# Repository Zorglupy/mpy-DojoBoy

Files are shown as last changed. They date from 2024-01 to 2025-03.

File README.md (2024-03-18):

# DojoBoy



The DojoBoy console is a DIY handheld game console project based on MicroPython

The main objectives of the project are:
- Cheap and easy to make with common components (no exotic components, custom PCB or universal PCB)
- Simple assembly with reduced tooling (soldering iron, screwdriver, Dremel tool)
- Easy printing of the case (5 parts only without supports)
- Game coding easy with only MicroPython libraries (no custom C codes, orginal MicroPython image based)
  - v 1.0 : All In One library
  - v 2.0 (WIP): Module with libraries (multiple objects) : object oriented coding, vector methods, extended features...

# Hardware

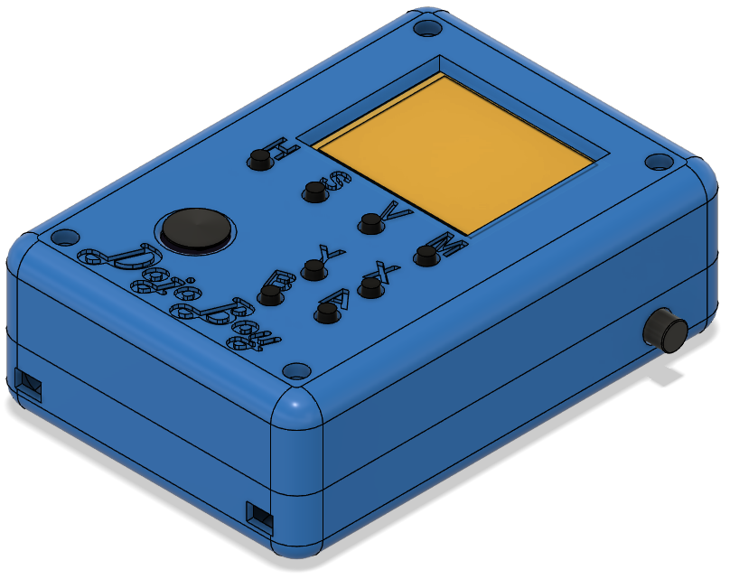
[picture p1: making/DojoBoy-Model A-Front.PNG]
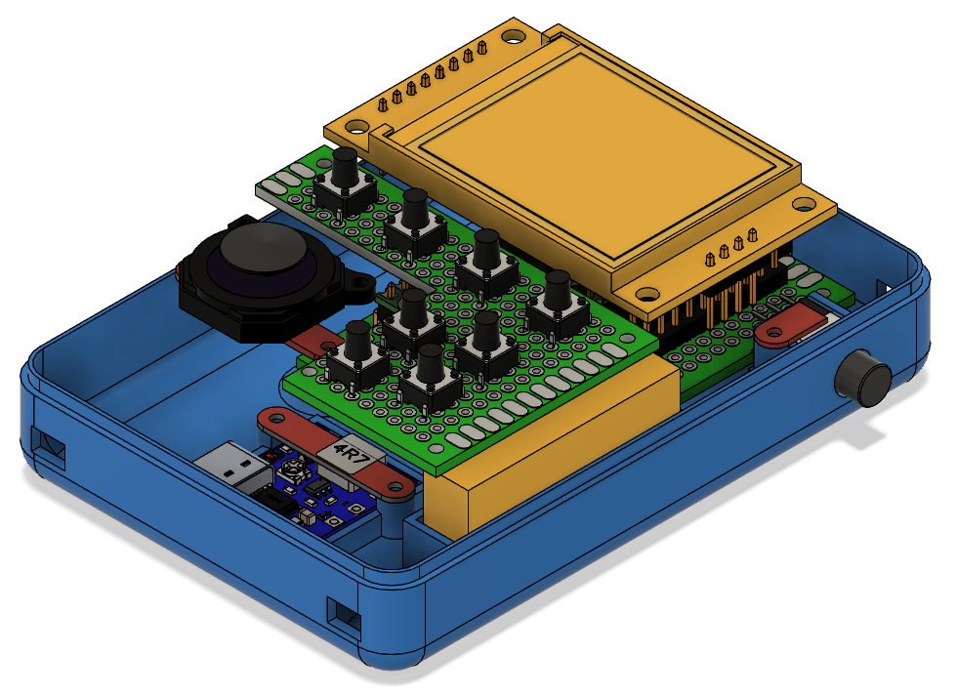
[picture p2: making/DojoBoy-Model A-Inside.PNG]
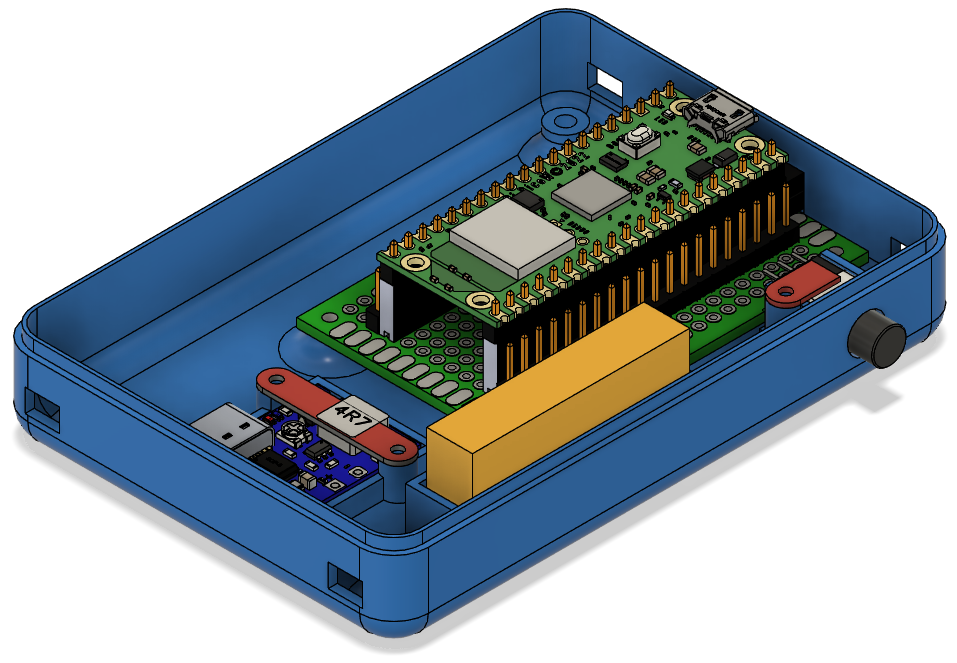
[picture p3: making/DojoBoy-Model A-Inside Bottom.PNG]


Multiple platforms are compatible/available:
- Raspberry Pi Pico or Pico W board and RP2040 clones
- LILYGO® T8 V1.7.1 ESP32 board.
- VCC-GND Studio YD-ESP32-S3 (DevKitC 1 clone)

Specs:
- Display:
  - ST7735 160x128 1.8"
  - ST7789 240x240 1.54"
  - ILI9341 320x240 3.2"
  - SSD1309 128x64 2.42"
- LiPo battery with charge management
- Joystick + 8 buttons
- 2 beeper channels (PWM)
- Expansion port (I2C, GPIO, I2S, SPI)
- SD card
- 3D Printable case

Schema :
DojoBoy-Wiring-Amp-Speaker-V2_bb

| Raspberry Pi Pico GPIO | Items Pin |
|--- |:-: |
| GPIO00 | A Button  |
| GPIO01 | B Button  |
| GPIO02 | X Button  |
| GPIO03 | Y Button  |
| GPIO04 | Ext Port - I2C 0 SDA |
| GPIO05 | Ext Port - I2C 0 SCL |
| GPIO06 | Home Button  |
| GPIO07 | Start Button  |
| GPIO08 | Volume Button  |
| GPIO09 | Menu Button  |
| GPIO10 | Ext Port - I2C 1 SDA  |
| GPIO11 | Ext Port - I2C 1 SCL  |
| GPIO12 | Display - SPI 1 A0 / DC  |
| GPIO13 | Display - SPI 1 CS  |
| GPIO14 | Display - SPI 1 SCK / CLK  |
| GPIO15 | Display - SPI 1 MOSI  |
| GPIO16 | Ext Port - SPI 0 MISO  |
| GPIO17 | Ext Port - SPI 0 CS  |
| GPIO18 | Ext Port - SPI 0 SCK / CLK  |
| GPIO19 | Ext Port - SPI 0 MOSI  |
| GPIO20 | Display - RST / Reset  |
| GPIO21 | PWM Sound Channel 0  |
| GPIO22 | PWM Sound Channel 1  |
| GPIO26 | Joystick X  |
| GPIO27 | Joystick Y  |
| GPIO28 | Display - LED  |
| 3.3V | Output 3.3V Power  |
| VSYS | Input 5V Power from Bat. Charger  |
| VBUS | Output 5V Power to Bat. Charger  |

# Wiring

DojoBoy-Board-V1_bb

# PCB
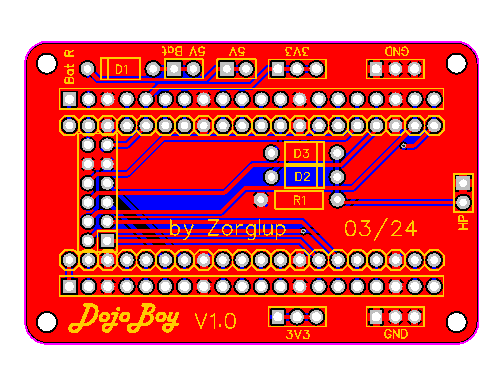
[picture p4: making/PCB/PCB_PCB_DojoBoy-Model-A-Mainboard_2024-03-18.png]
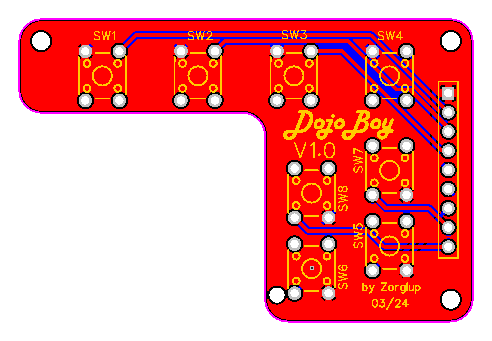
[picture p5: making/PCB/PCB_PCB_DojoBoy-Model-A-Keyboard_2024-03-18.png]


# Software

See Cheat Sheet file in Doc folder... 

Sources and inspirations :

- https://gist.github.com/samneggs
- https://github.com/harlepengren/PicoGame
- https://github.com/YouMakeTech/Pi-Pico-Game-Boy
- https://github.com/HalloSpaceBoy5/PicoBoy
- https://github.com/MLXXXp/Arduboy2
- https://github.com/peterhinch
- https://github.com/mchobby
- and more....

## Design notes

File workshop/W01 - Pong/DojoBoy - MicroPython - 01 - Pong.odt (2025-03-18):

DojoBoy - Pong

Cet atelier a pour objectif d’examiner les bases de la programmation en Micropython (Python) de la console DojoBoy et de créer un jeu inspiré du jeu Pong.

Au terme de celui-ci, tu seras capable de :

- Initialiser la console
- Afficher un objet à l’écran
- Déplacer un objet à l’écran
- Faire une boucle finie et infinie
- Utiliser les boutons de la console
- Définir une fonction

Pour comprendre les étapes de cet atelier, il est préférable que tu aies déjà appris les bases de la programmation avec Scratch et que tu comprennes ce qu’est une « variable », une « condition » et une « boucle ».

Le code dans ces pages n’est pas complet. Il est indispensable d’ajouter et adapter le code pour arriver à l’objectif. Fais-toi aider par un coach si tu es perdu ou que tu ne comprends pas !

Les challenge en fin d’étapes vont te permette d’expérimenter ton code et de mieux le comprendre. Ne les passe pas trop vite… 😉

# Initialisation du DojoBoy

L’accès aux fonctions qui permettent d’utiliser l’écran, les boutons et le son de la console sont rassemblés dans un « objet ».

Tous les programmes que tu vas écrire pour la console devront commencer par « importer » cet objet (rendre disponible l’objet pour le code qui va suivre). Il faut donc commencer les programmes par les lignes suivantes.

from dojoboy_v1 import DojoBoy

Cette ligne signifie qu’il faut importer l’objet « Dojo Boy » qui se trouve dans le module « dojoboy_v1 ». Nous examinerons dans un autre atelier ce qu’est un « module » et un « objet » dans le langage Python. Ne t’y attarde pas maintenant 😉

Il faut ensuite « instancier » cet objet (créer cet objet et lui donner un nom) pour ensuite l’utiliser dans nos programmes. Lors de la création de cet objet, des paramètres de configuration seront ajoutés pour configurer l’écran et les boutons de la console.

Quelques paramètres sont disponibles pour définir des paramètres particuliers.

Il n’est pas utile de s’étendre sur tous ces paramètres. Un seul est pratique pour débuter, il s’agit du paramètre pour activer ou désactiver l’écran d’accueil au démarrage d’un programme.

Pour créer l’objet DojoBoy avec l’écran d’accueil, il faut utiliser la commande suivante :

djb = DojoBoy()

Pour l’objet DojoBoy sans l’écran d’accueil:

djb=DojoBoy(show_intro=False)

Maintenant, commençons à programmer la console ! 👍

# Etape 1 : Premier programme...

Commençons par examiner comment afficher une « balle » à l’écran...

Les premières commandes du programme vont définir la position où la balle doit être affichée sur l’écran.

Nous allons donc définir les variables pos_x et pos_y et les initialiser avec les valeurs de la position sur la grille de pixels de l’écran.

L’illustration suivante représente l’écran de la console. Le pixel à la position 0,0 se trouve en haut à gauche. L’axe des X est horizontal (la largeur de l’écran, « width » en anglais) et l’axe Y est vertical (la hauteur de l’écran, « height » en anglais).

L’écran du DojoBoy est composé suivant le type d’écran de 240 ou 160 points sur la largeur et 240 ou 128 points sur la hauteur.

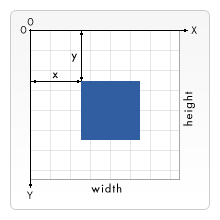
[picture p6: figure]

Pour afficher la balle au milieu de l’écran 160x128 points, il faut donc initialiser les variables de la manière suivante :

pos_x = 80

pos_y = 64

Il faut ensuite définir le diamètre en point (pixel) de la balle.

ball_size = 3 # ball radius

On peut remarquer en fin de ligne le caractère # qui permet d’ajouter des commentaires dans le programme. Tout ce qui suit ce caractère sur une même ligne n’est pas pris en compte dans le programme.

Les lignes suivantes vont ensuite afficher une balle au centre de l’écran.

djb.display.ellipse(pos_x, pos_y, ball_size, ball_size, djb.display.RED_H, True) #draw ball

djb.display.show() # show screen

La fonction « djb.display.ellipse » signifie « dessine sur l’écran de la console » (djb.display) « un ovale » (ellipse). Ici, c’est un ovale particulier car il a la forme d’un cercle.

Les paramètres qui suivent se basent sur les variables définies avant.

- pos_x : position du centre du cercle sur l’axe X
- pos_y : position du center du cercle sur l’axe Y
- ball_size,ball_size : défini le rayon du cercle
- djb.display.RED_H : défini la couleur de cercle
- True : indique le cercle doit être rempli de couleur

La fonction précédente ne montre pas directement le contenu de l’écran. Il faut utiliser la fonction djb.display.show() pour cela.

Challenge

- Change la couleur de la balle
- Change la taille de la balle
- Affiche la balle dans le haut de l’écran
- Affiche la balle à gauche de l’écran
- Affiche trois balles réparties sur l’écran

# Etape 2 : Déplacement d’une forme sur l’écran

Le début du programme est identique à celui de l’étape précédente.

pos_x = 80

pos_y = 64

ball_size = 3 # ball radius

djb.display.fill(djb.display.BLACK)

Cette ligne permet de remplir l’écran (fill en anglais) avec de la couleur noire.

for x in range (0,150,1): # loop from 0 to 150 by step 1

djb.display.ellipse(x, pos_y, ball_size, ball_size, djb.display.RED_H, True) #draw ball

djb.display.show() # show screen

Ces lignes permettent de créer une boucle (for en anglais). La variable x est donc incrémentée (augmentée) d’une unité en commençant à 0 jusque 150 (range (0,150,1).

Il faut remarquer que les lignes suivantes sont décalées vers la droite. Ce décalage permet de définir les commandes qui font partie de la boucle. Ce décalage s’appelle une « indentation ». La façon la plus simple pour créer cette indentation est d’utiliser la touche Tabulation (à gauche de la touche A sur le clavier).

Challenge

- Adapte le code pour afficher la balle sans sa trace
- Augmente la vitesse de la balle
- Déplace la balle en diagonale
- Déplace la balle en diagonale mais plus rapidement horizontalement que verticalement

# Etape 3 : Déplacement sans fin de la balle

Adapte le programme de l’étape précédente avec les lignes suivantes.

pos_x = 80

pos_y = 64

ball_size = 3 # ball radius

while True:

pos_x += 1

djb.display.ellipse(pos_x, pos_y, ball_size, ball_size, djb.display.RED_H, True) #draw ball

djb.display.show() # show screen

La différence avec le programme précédent est la ligne avec la commande while (« Tant que » en français). Associé avec la condition True, cette commande permet de créer une boucle infinie (qui ne s’arrête jamais). Comme pour la boucle for, les lignes suivantes font partie de la boucle et sont donc indentés.

Challenge

- Adapte le code pour afficher la balle de gauche à droite et de droite à gauche en la faisant rebondir sur le côté droit et gauche
- Dessine un rectangle bleu sur le périmètre de l’écran avec la commande djb.display.rect(pos_x,pos_y,largeur,hauteur, couleur, remplissage).
- Adapte le code pour déplacer la balle à l’intérieur du rectangle en la faisant rebondir sur ses bords

# Etape 4 : Utilisation des boutons

Déplaçons la balle avec les boutons directionnels

pos_x = 80

pos_y = 64

ball_size = 3 # ball radius

while True:

djb.scan_jst_btn() #scan le joystick et les buttons

La ligne précédente permet de vérifier si le joystick a été déplacé ou si un bouton a été pressé. La ligne suivante permet de vérifier si le bouton indiqué a été pressé. Elle utilise la commande if (« si » en français). Ici, si le bouton directionnel droit est pressé ou si le joystick est déplacé vers la droite la commande de la ligne suivante est exécutée.

Remarque que cette ligne est indentée. Elle permet d’incrémenter (augmenter) d’une unité la variable pos_x. Cette ligne équivalente à pos_x = pos_x + 1.

if djb.pressed(djb.btn_Right): # if right button pressed

pos_x += 1

djb.display.ellipse(pos_x, pos_y, ball_size, ball_size, djb.display.RED_H, True) #draw ball

djb.display.show() # show screen

Challenge

- Adapte le code pour déplacer la balle à gauche et à droite avec les boutons directionnels ou le joystick.
- Adapte le code pour déplacer la balle dans toutes les directions avec les boutons directionnels

# Etape 5 : Création d’une fonction

Améliorons le code avec l’utilisation des fonctions (méthodes).

Les deux lignes suivantes permettent de définir une fonction. La commande def est suivie du nom de la fonction (« draw_ball(x,y) »). L’utilisation d’une fonction permet d’éviter l’écriture répétitive d’un ensemble de commandes dans un programme. Cela permet aussi de rendre plus lisible ton programme.

Ici, draw_ball(x,y) permet de remplacer la commande pour dessiner le cercle à l’écran. Les paramètres x et y permettent de définir la position du cercle sur l’écran.

def draw_ball(x,y):

djb.display.ellipse(x, y, ball_size, ball_size, djb.display.RED_H, True) #draw ball

while True:

djb.scan_jst_btn() #scan buttons

if djb.pressed(djb.btn_Right): # if right button pressed

pos_x += 1

draw_ball(pos_x,pos_y)

djb.display.show() # show screen

Challenge

- Adapte le code pour déplacer la balle dans toutes les directions avec les boutons directionnels
- Adapte la fonction pour modifier la couleur de la balle lorsqu’on appuie sur le bouton A

# Etape 6 : Changement de la vitesse de déplacement

Ajoutons une fonction pour gérer la vitesse de déplacement de la balle.

A côté des valeurs pour définir la position de la balle à l’écran (pos_x et pos_y), d’autres valeurs sont utilisées pour déterminer la vitesse (velocity en anglais) de déplacement sur l’axe X et Y(variables velocity_x et velocity_y). Plus ces valeurs sont élevées, plus le déplacement sera rapide.

La direction du déplacement de la balle sur les axes X et Y est déterminée par le signe + ou – appliqué aux variables de vitesse (exemple : -velocity_x ou +velocity_y).

Pour convertir la direction appliquée sur le joystick ou les boutons de direction, les variables de vitesse seront multipliées par 1 ou -1. Ainsi, pour un déplacement vers la droite, on multipliera la vitesse de l’axe X par 1. Vers le haut, on multipliera la vitesse de l’axe Y par -1.

pos_x = 80

pos_y = 64

ball_size = 3 # ball radius

velocity_x = 2

direction_x = 0

def draw_ball(x,y):

djb.display.fill(djb.display.BLACK) # screen cleaning

djb.display.ellipse(x, y, ball_size, ball_size, djb.display.RED_H, True) #draw ball

def move(p_x,p_y,vel_x,vel_y,dir_x,dir_y):

p_x += vel_x * dir_x

p_y += vel_y * dir_y

return p_x,p_y

while True:

direction_x = 0

djb.scan_jst_btn() #scan buttons

if djb.pressed(djb.btn_Right): # if right button pressed

direction_x = 1

pos_x,pos_y = move(pos_x,pos_y,velocity_x,0,direction_x,0)

draw_ball(pos_x,pos_y)

djb.display.show() # show screen

Challenge

- Adapte le code pour que la balle se déplace dans toutes les directions avec des rebonds sur le périmètre de l’écran
- Adapte le code pour diminuer la vitesse de la balle sur l’axe X avec le bouton gauche
- Adapte le code pour augmenter et diminuer la vitesse de la balle sur l’axe Y avec les boutons haut et bas

# Etape 7 : Rebond sur les bords

Ajoutons une fonction pour gérer les rebonds de la balle sur un cadre

pos_x = 80

pos_y = 64

ball_size = 3 # ball radius

velocity_x = 1

velocity_y = 1

direction_x = -1

direction_y = 1

outline_x = 30 # pos x du coin superieur gauche du cadre

outline_y = 20 # pos y du coin superieur gauche du cadre

outline_w = 80 # largeur du cadre

outline_h = 60 # hauteur du cadre

def draw_ball(x,y):

djb.display.fill(djb.display.BLACK) # screen cleaning

# draw ball

djb.display.ellipse(x, y, ball_size, ball_size, djb.display.RED_H, True)

# draw border

djb.display.rect(outline_x, outline_y, outline_w, outline_h, djb.display.BLUE_H)

def move(p_x,p_y,vel_x,vel_y,dir_x,dir_y):

p_x += vel_x * dir_x

p_y += vel_y * dir_y

return p_x,p_y

def bounce(pos,dir,border_low,border_high): # rebond de la balle

if pos <= border_low and dir == -1: # rebond gauche ou haut

dir = 1

elif pos >= border_high and dir == 1: # rebond droit ou bas

dir = -1

return dir

while True:

djb.scan_jst_btn() #scan buttons

if djb.pressed(djb.btn_Right): # if right button pressed

direction_x = 1

direction_x = bounce(pos_x,direction_x,outline_x,outline_x + outline_w)

direction_y = bounce(pos_y,direction_y,outline_y,outline_y + outline_h)

pos_x,pos_y = move(pos_x,pos_y,velocity_x,velocity_y,direction_x,direction_y)

draw_ball(pos_x,pos_y)

djb.display.show() # show screen

# Etape 8 : Utilisation des contrôles de direction pour modifier la vitesse

pos_x = 80

pos_y = 64

ball_size = 3 # ball radius

velocity_x = 1

velocity_y = 1

direction_x = -1

direction_y = 1

outline_x = 30

outline_y = 20

outline_w = 80

outline_h = 60

def draw_ball(x,y):

djb.display.fill(djb.display.BLACK) # screen cleaning

# draw ball

djb.display.ellipse(x, y, ball_size, ball_size, djb.display.RED_H, True)

# draw border

djb.display.rect(outline_x, outline_y, outline_w, outline_h, djb.display.BLUE_H)

def move(p_x,p_y,vel_x,vel_y,dir_x,dir_y):

p_x += vel_x * dir_x

p_y += vel_y * dir_y

return p_x,p_y

def bounce(pos,dir,border_low,border_high): # rebond de la balle

if pos <= border_low and dir == -1: # rebond gauche ou haut

dir = 1

elif pos >= border_high and dir == 1: # rebond droit ou bas

dir = -1

return dir

while True:

djb.scan_jst_btn() #scan buttons

if djb.pressed(djb.btn_Right) and velocity_x < 10: # if right button pressed

velocity_x += 1

if djb.pressed(djb.btn_Left) and velocity_x > 0: # if left button pressed

velocity_x -= 1

if djb.pressed(djb.btn_Up) and velocity_y < 10: # if up button pressed

velocity_y += 1

if djb.pressed(djb.btn_Down) and velocity_y > 0: # if down button pressed

velocity_y -= 1

direction_x = bounce(pos_x,direction_x,outline_x + ball_size + velocity_x,outline_x + outline_w - ball_size - velocity_x)

direction_y = bounce(pos_y,direction_y,outline_y + ball_size + velocity_y,outline_y + outline_h - ball_size - velocity_y)

pos_x,pos_y = move(pos_x,pos_y,velocity_x,velocity_y,direction_x,direction_y)

draw_ball(pos_x,pos_y)

djb.display.show_and_wait() # show screen and wait...

# Etape 9 : On dessine la raquette...

pos_paddle_x = 80

pos_paddle_y = 118

paddle_w = 16

paddle_h = 8

pos_x = 80

pos_y = 64

ball_size = 3 # ball radius

velocity_x = 1

velocity_y = 1

direction_x = 1

direction_y = 1

outline_x = 30

outline_y = 20

outline_w = 100

outline_h = 60

def draw_border(): # draw border

djb.display.rect(outline_x, outline_y, outline_w, outline_h, djb.display.BLUE_H)

def draw_ball(x,y): # draw ball

djb.display.ellipse(x, y, ball_size, ball_size, djb.display.RED_H, True)

def draw_paddle(x): # dessine la raquette

djb.display.rect(x, pos_paddle_y, paddle_w, paddle_h, djb.display.GREEN_H, True)

def move(p_x,p_y,vel_x,vel_y,dir_x,dir_y):

p_x += vel_x * dir_x

p_y += vel_y * dir_y

return p_x,p_y

def bounce(pos,dir,border_low,border_high): # rebond de la balle

if pos <= border_low and dir == -1: # rebond gauche ou haut

dir = 1

elif pos >= border_high and dir == 1: # rebond droit ou bas

dir = -1

return dir

while True:

djb.scan_jst_btn() #scan buttons

if djb.pressed(djb.btn_Right) and velocity_x < 10: # if right button pressed

velocity_x += 1

if djb.pressed(djb.btn_Left) and velocity_x > 0: # if left button pressed

velocity_x -= 1

if djb.pressed(djb.btn_Up) and velocity_y < 10: # if up button pressed

velocity_y += 1

if djb.pressed(djb.btn_Down) and velocity_y > 0: # if down button pressed

velocity_y -= 1

direction_x = bounce(pos_x,direction_x,outline_x + ball_size + velocity_x,outline_x + outline_w - ball_size - velocity_x)

direction_y = bounce(pos_y,direction_y,outline_y + ball_size + velocity_y,outline_y + outline_h - ball_size - velocity_y)

pos_x,pos_y = move(pos_x,pos_y,velocity_x,velocity_y,direction_x,direction_y)

draw_border()

draw_paddle(pos_paddle_x)

draw_ball(pos_x,pos_y)

djb.display.show_and_wait(True) # show screen and wait...

# Etape 10

pos_paddle_x = 80

pos_paddle_y = 118

paddle_w = 16

paddle_h = 8

velocity_paddle = 2

pos_x = 80

pos_y = 64

ball_size = 3 # ball radius

velocity_x = 0

velocity_y = 0

direction_x = 1

direction_y = 1

outline_x = 0

outline_y = 20

outline_w = 120

outline_h = 108

def draw_border():

djb.display.rect(outline_x, outline_y, outline_w, outline_h, djb.display.BLUE_H) # draw border

def draw_ball(x,y):

djb.display.ellipse(x, y, ball_size, ball_size, djb.display.RED_H, True) # draw ball

def draw_paddle(x):

djb.display.rect(x, pos_paddle_y, paddle_w, paddle_h, djb.display.GREEN_H, True)

def move(p_x,p_y,vel_x,vel_y,dir_x,dir_y):

p_x += vel_x * dir_x

p_y += vel_y * dir_y

return p_x,p_y

def bounce(pos,dir,border_low,border_high): # rebond de la balle

if pos <= border_low and dir == -1: # rebond gauche ou haut

dir = 1

elif pos >= border_high and dir == 1: # rebond droit ou bas

dir = -1

return dir

while True:

djb.scan_jst_btn() #scan buttons

if djb.pressed(djb.btn_Right) and velocity_x < 10: # if right button pressed

velocity_x += 1

if djb.pressed(djb.btn_Left) and velocity_x > 0: # if left button pressed

velocity_x -= 1

if djb.pressed(djb.btn_Up) and velocity_y < 10: # if up button pressed

velocity_y += 1

if djb.pressed(djb.btn_Down) and velocity_y > 0: # if down button pressed

velocity_y -= 1

direction_x = bounce(pos_x,direction_x,outline_x + ball_size + velocity_x,outline_x + outline_w - ball_size - velocity_x)

direction_y = bounce(pos_y,direction_y,outline_y + ball_size + velocity_y,outline_y + outline_h - ball_size - velocity_y)

pos_x,pos_y = move(pos_x,pos_y,velocity_x,velocity_y,direction_x,direction_y)

draw_border()

draw_paddle(pos_paddle_x)

draw_ball(pos_x,pos_y)

djb.display.show_and_wait(True) # show screen and wait...

# Etape 11 : Déplacement de la raquette

pos_paddle_x = 80

pos_paddle_y = 118

paddle_w = 16

paddle_h = 8

velocity_paddle = 2

pos_x = 80

pos_y = 64

ball_size = 3 # ball radius

velocity_x = 0

velocity_y = 0

direction_x = 1

direction_y = 1

outline_x = 0

outline_y = 20

outline_w = 120

outline_h = 108

def draw_border():

djb.display.rect(outline_x, outline_y, outline_w, outline_h, djb.display.BLUE_H)

def draw_ball(x,y):

djb.display.ellipse(x, y, ball_size, ball_size, djb.display.RED_H, True)

def draw_paddle(x):

djb.display.rect(x, pos_paddle_y, paddle_w, paddle_h, djb.display.GREEN_H, True)

def move(p_x,p_y,vel_x,vel_y,dir_x,dir_y):

p_x += vel_x * dir_x

p_y += vel_y * dir_y

return p_x,p_y

def bounce(pos,dir,border_low,border_high): # rebond de la balle

if pos <= border_low and dir == -1: # rebond gauche ou haut

dir = 1

elif pos >= border_high and dir == 1: # rebond droit ou bas

dir = -1

return dir

while True:

djb.scan_jst_btn() #scan buttons

# if right button pressed

if djb.pressed(djb.btn_Right) and pos_paddle_x < outline_x + outline_w - paddle_w:

pos_paddle_x += velocity_paddle

# if left button pressed

if djb.pressed(djb.btn_Left) and pos_paddle_x > 0:

pos_paddle_x -= velocity_paddle

# if up button pressed

if djb.pressed(djb.btn_Up) and velocity_y < 10:

velocity_y += 1

# if down button pressed

if djb.pressed(djb.btn_Down) and velocity_y > 0:

velocity_y -= 1

# check ball bounce on border

direction_x = bounce(pos_x,direction_x,outline_x + ball_size + velocity_x,outline_x + outline_w - ball_size - velocity_x)

direction_y = bounce(pos_y,direction_y,outline_y + ball_size + velocity_y,outline_y + outline_h - ball_size - velocity_y)

# check ball bounce on paddle

#direction_x = bounce(pos_x,direction_x,outline_x + ball_size + velocity_x,pos_x + outline_w - ball_size – velocity_x)

if pos_paddle_x < pos_x < pos_paddle_x + paddle_w and pos_y + ball_size >= pos_paddle_y:

direction_y = bounce(pos_y,direction_y,0,pos_paddle_y - ball_size - velocity_y)

pos_x,pos_y = move(pos_x,pos_y,velocity_x,velocity_y,direction_x,direction_y)

draw_border()

draw_paddle(pos_paddle_x)

draw_ball(pos_x,pos_y)

djb.display.show_and_wait(True) # show screen and wait...

# Etape 12 : Rebond sur la raquette

Ajout de la détection de la sortie de balle

pos_paddle_x = 80

pos_paddle_y = 118

paddle_w = 16

paddle_h = 8

velocity_paddle = 2

pos_x = 80

pos_y = 64

ball_size = 3 # ball radius

velocity_x = 0

velocity_y = 2

direction_x = 1

direction_y = 1

outline_x = 0

outline_y = 20

outline_w = 120

outline_h = 108

def draw_border():

djb.display.rect(outline_x, outline_y, outline_w, outline_h, djb.display.BLUE_H) # draw border

def draw_ball(x,y):

djb.display.ellipse(x, y, ball_size, ball_size, djb.display.RED_H, True) # draw ball

def draw_paddle(x):

djb.display.rect(x, pos_paddle_y, paddle_w, paddle_h, djb.display.GREEN_H, True)

def move(p_x,p_y,vel_x,vel_y,dir_x,dir_y):

p_x += vel_x * dir_x

p_y += vel_y * dir_y

return p_x,p_y

def bounce(pos,dir,border_low,border_high): # rebond de la balle

if pos <= border_low and dir == -1: # rebond gauche ou haut

dir = 1

elif pos >= border_high and dir == 1: # rebond droit ou bas

dir = -1

return dir

while True:

djb.scan_jst_btn() #scan buttons

if djb.pressed(djb.btn_Right) and pos_paddle_x < outline_x + outline_w - paddle_w: # if right button pressed

pos_paddle_x += velocity_paddle

if djb.pressed(djb.btn_Left) and pos_paddle_x > 0: # if left button pressed

pos_paddle_x -= velocity_paddle

# check ball bounce on border

direction_x = bounce(pos_x,direction_x,outline_x + ball_size + velocity_x,outline_x + outline_w - ball_size - velocity_x)

direction_y = bounce(pos_y,direction_y,outline_y + ball_size + velocity_y,outline_y + outline_h - ball_size - velocity_y)

# check paddle bounce

if pos_paddle_x < pos_x < pos_paddle_x + paddle_w and pos_y + ball_size >= pos_paddle_y:

direction_y = bounce(pos_y,direction_y,0,pos_paddle_y - ball_size - velocity_y)

if pos_paddle_x < pos_x < pos_paddle_x + (paddle_w//3):

velocity_x = 2

direction_x = -1

if pos_paddle_x + (paddle_w//3) < pos_x < pos_paddle_x + 2 * (paddle_w//3):

velocity_x = 0

if pos_paddle_x + 2 * (paddle_w//3) < pos_x < pos_paddle_x + paddle_w:

velocity_x = 2

direction_x = 1

# check if losing

if pos_y + ball_size + velocity_y >= outline_y + outline_h:

djb.display.text('Game Over',40,64,djb.display.RED_H)

djb.display.show()

break

pos_x,pos_y = move(pos_x,pos_y,velocity_x,velocity_y,direction_x,direction_y)

draw_border()

draw_paddle(pos_paddle_x)

draw_ball(pos_x,pos_y)

djb.display.show_and_wait(True) # show screen and wait...

# Etape 13 : Ajout cible et score

Ajout de d’une fonction de collision de la balle avec la cible

import math

score = 0

pos_paddle_x = 80

pos_paddle_y = 118

paddle_w = 16

paddle_h = 8

speed_paddle = 2

pos_x = 80

pos_y = 64

ball_size = 3 # ball radius

speed_x = 0

speed_y = 2

dir_x = 1

dir_y = 1

outline_x = 0

outline_y = 20

outline_w = 120

outline_h = 108

def draw_border():

djb.display.rect(outline_x, outline_y, outline_w, outline_h, djb.display.BLUE_H) # draw border

def draw_ball(x,y):

djb.display.ellipse(x, y, ball_size, ball_size, djb.display.RED_H, True) # draw ball

def draw_paddle(x):

djb.display.rect(x, pos_paddle_y, paddle_w, paddle_h, djb.display.GREEN_H, True)

def draw_target(x,y):

djb.display.ellipse(x, y, 10, 10, djb.display.MAGENTA_H, True)

def draw_score():

djb.display.text('Score:', 10, 0, djb.display.WHITE_H)

djb.display.text(str(score), 60, 0, djb.display.WHITE_H)

def move(x,y,s_x,s_y,d_x,d_y):

x += s_x * d_x

y += s_y * d_y

return x,y

def bounce(v,d_v,b_low_v,b_high_v):

if v <= b_low_v:

d_v = -d_v

elif v >= b_high_v:

d_v = -d_v

return d_v

def collide(x,y):

distance = int(math.sqrt((x - (outline_x + outline_w)//2) ** 2 + (y - 40) ** 2))

print(distance)

if distance < 10:

return distance

return 0

while True:

djb.scan_jst_btn() #scan buttons

if djb.pressed(djb.btn_Right) and pos_paddle_x < outline_x + outline_w - paddle_w: # if right button pressed

pos_paddle_x += speed_paddle

if djb.pressed(djb.btn_Left) and pos_paddle_x > 0: # if left button pressed

pos_paddle_x -= speed_paddle

# check border bounce

dir_x = bounce(pos_x,dir_x,outline_x + ball_size + speed_x,outline_x + outline_w - ball_size - speed_x)

dir_y = bounce(pos_y,dir_y,outline_y + ball_size + speed_y,outline_y + outline_h - ball_size - speed_y)

# check paddle bounce

if pos_paddle_x < pos_x < pos_paddle_x + paddle_w and pos_y + ball_size >= pos_paddle_y:

dir_y = bounce(pos_y,dir_y,0,pos_paddle_y - ball_size - speed_y)

if pos_paddle_x < pos_x < pos_paddle_x + (paddle_w//3):

speed_x = 2

dir_x = -1

if pos_paddle_x + (paddle_w//3) < pos_x < pos_paddle_x + 2 * (paddle_w//3):

speed_x = 0

if pos_paddle_x + 2 * (paddle_w//3) < pos_x < pos_paddle_x + paddle_w:

speed_x = 2

dir_x = 1

# check if losing

if pos_y + ball_size + speed_y >= outline_y + outline_h:

djb.display.text('Game Over',40,64,djb.display.RED_H)

djb.display.show()

break

# check collide with target

score += collide(pos_x,pos_y)

pos_x,pos_y = move(pos_x,pos_y,speed_x,speed_y,dir_x,dir_y)

draw_border()

draw_paddle(pos_paddle_x)

draw_target((outline_x + outline_w)//2,40)

draw_ball(pos_x,pos_y)

draw_score()

djb.display.show_and_wait(True) # show screen and wait...

# Infos générales

Auteur : CoderdojoBelgium - Date de publication : 01-2024 - CC-BY-NC-SA (http://creativecommons.org/licenses/by-nc-sa/3.0/)

Site web : www.coderdojobelgium.be - Contact : info@coderdojobelgium.be

ABOVE ALL, BE COOL!

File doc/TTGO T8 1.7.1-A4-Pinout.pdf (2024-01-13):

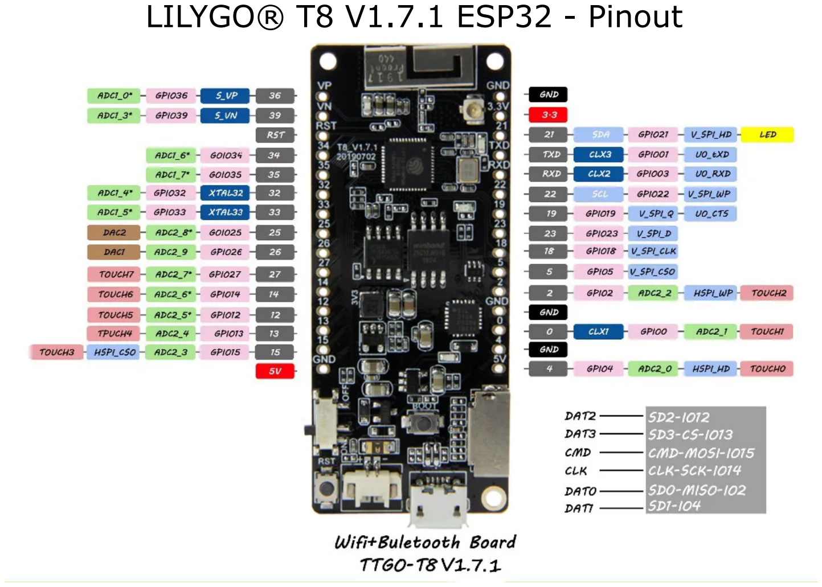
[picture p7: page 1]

LILYGO® T8 V1.7.1 ESP32 - Pinout

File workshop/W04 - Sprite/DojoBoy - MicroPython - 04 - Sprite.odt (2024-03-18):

4 - DojoBoy – Sprite

Cet atelier a pour objectif de créer des sprites à partir de fichiers image PNG. Ces sprites pourront ensuite être utilisé dans des jeux ou applications.

Sprite ?!? Les sprites sont des images qui sont intégrées à des jeux ou des applications pour représenter des éléments ou personnages. Ils peuvent aussi être utilisés pour créer l’animation d’un personnage par exemple (lorsqu’il marche, se déplace ou explose…)

Vu les capacités limitées du DojoBoy, il est indispensable de les fabriquer pour qu’ils prennent le moins de mémoire possible.

Il est possible d’intégrer des sprites avec une palette de 65000 couleurs ou 1 couleur (1 couleur = monochrome). La création des sprites doit se faire à partir de fichiers images au format PNG. On peut créer ces images à partir d’une application de dessin ou en les téléchargeant à partir d’Internet.

# Etapes de création

Les étapes à suivre pour la création d’un sprite pour DojoBoy sont les suivantes :

- Création de l’image source
- Sauvegarde de l’image dans le format PNG adapté
- Conversion de l’image dans le format « DojoBoy »
- Importation du fichier sprite dans la console
- Utilisation du sprite dans le jeu ou l’application

# Création d’image pour les sprites

Beaucoup d’applications existent pour créer des images. Pour cet atelier nous allons une application qui est présente sur tous les PC : Paint.

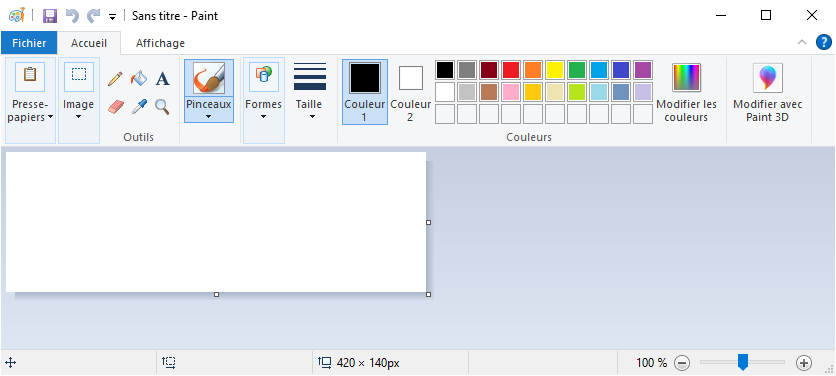
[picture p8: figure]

Après l’ouverture de l’application, il est maintenant nécessaire de définir la taille en pixel de notre sprite. La taille doit être adaptée à l’écran du DojoBoy qui mesure 160 pixels de large sur 128 pixels de haut. Nous allons pour commencer définir un sprite qui fera 16 pixels de large sur 16 pixels de haut (16x16).

Pour définir la taille de notre sprite, il faut se rendre dans le menu ‘Image’ puis ‘Redimensionner’

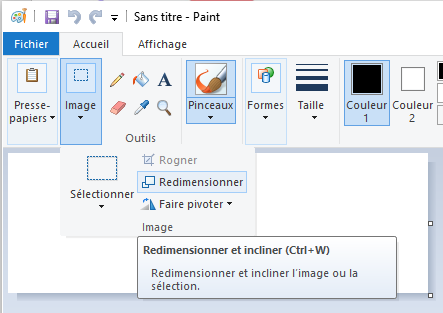
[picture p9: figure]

Adapte ensuite la taille :

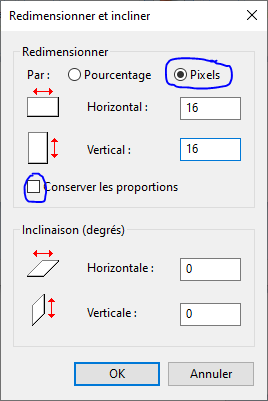
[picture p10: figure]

Il est ensuite possible d’agrandir l’image pour faciliter le dessin de l’image.

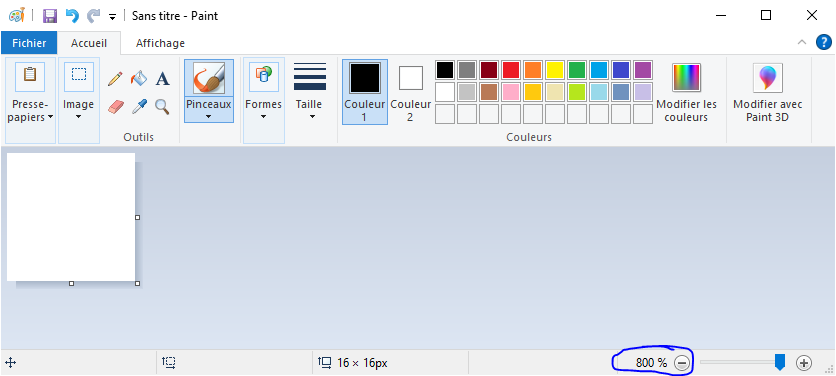
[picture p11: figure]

Amuse-toi ensuite à dessiner ton sprite.

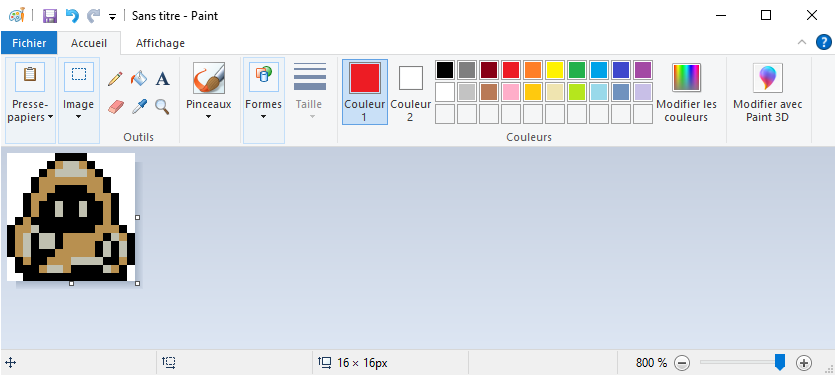
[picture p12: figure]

Il faut ensuite sauvegarder vote sprite dans un fichier en veillant a ce qu’il soit au format PNG.

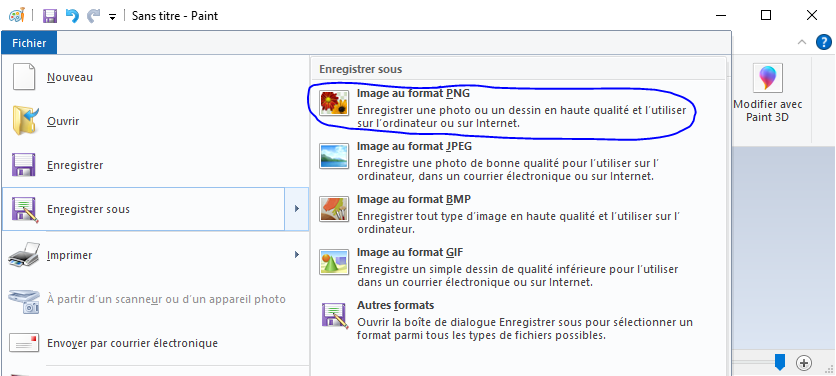
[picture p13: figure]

Sauvegarde ton fichier dans le dossier ‘Images’ de votre ordinateur.

# Conversion de l’image

La conversion du fichier PNG nécessite l’utilisation d’un script Python qui doit d’abord être installé sur ta machine. Il faut aussi que python soit aussi installé sur ta machine (cette opération n’est pas expliquée dans cet atelier, demande de l’aide à ton coach s’il n’est pas présent sur ton ordinateur)

Le script Python pour la conversion doit d’abord être installé sur ton ordinateur. Il faut le télécharger à l’adresse :

https://github.com/Zorglupy/mpy-DojoBoy/tree/main/tool/XXXXX.py

Sauvegarde le script dans le dossier ‘Images’ de ton ordinateur (le même dossier que ton fichier PNG).

Ouvre maintenant une invite de commandes (menu ‘Démarrer’ puis tape la commande ‘cmd’), puis tape la commande ‘cd Pictures’ ou ‘cd Images’ pour te placer dans le dossier ‘Images’.

Il faut ensuite taper la commande :

python png2gbrgb565.py MonSprite.png MonSprite.bin

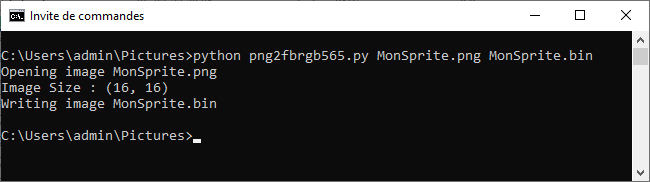
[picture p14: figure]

Ton sprite est maintenant prêt pour être utiliser sur ton DojoBoy !

# Import du sprite sur le DojoBoy

Ouvre ‘Thonny’ et connecte ton DojoBoy pour qu’il soit reconnu. Si le volet ‘Fichiers’ n’est pas visible, active-le.

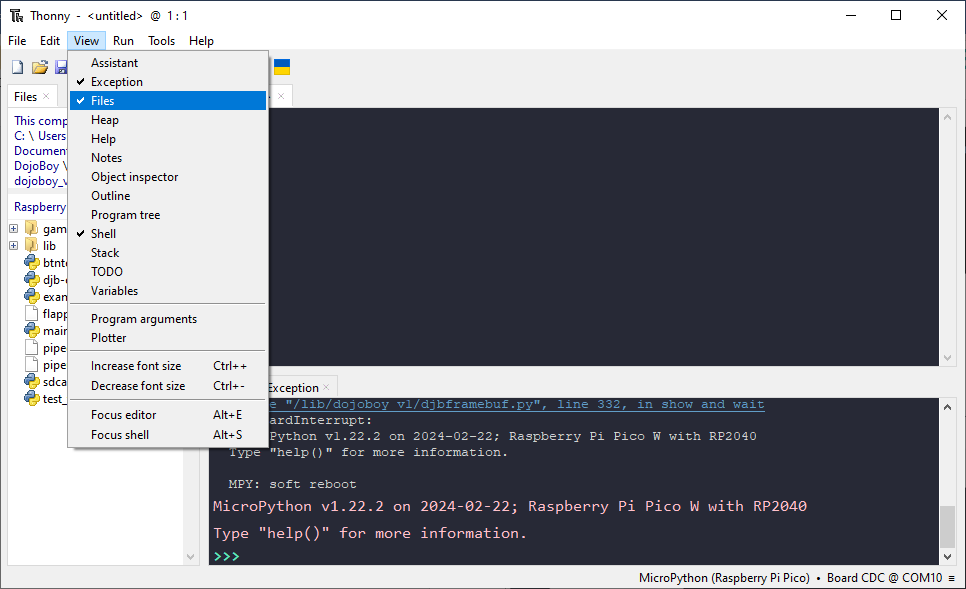
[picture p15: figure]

Rends-toi dans le dossier ‘Images’ ou se trouve ton sprite.

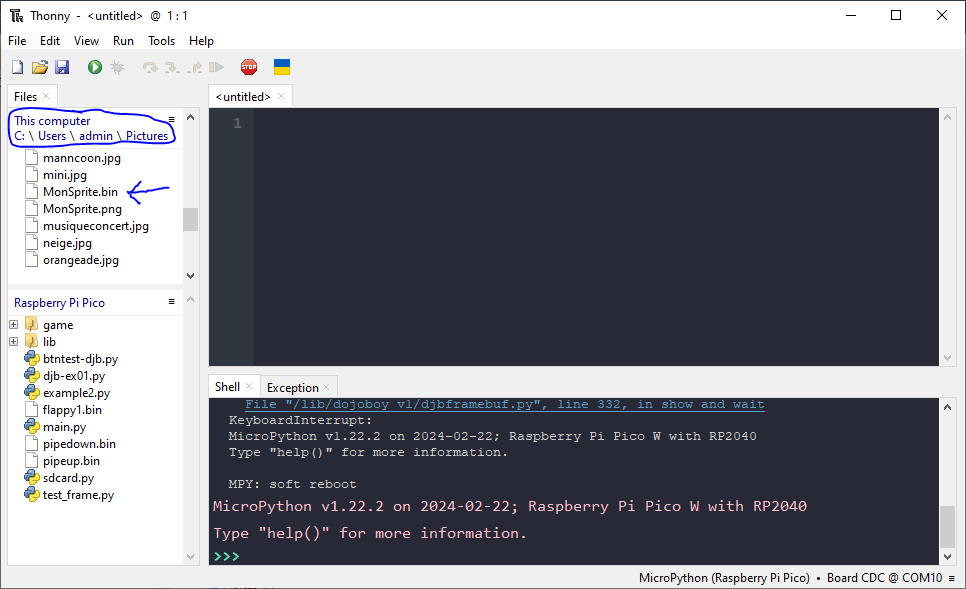
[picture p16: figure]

Sélectionne le fichier MonSprite.bin, fais une clic droit puis ‘Upload’ pour copier ton sprite sur le DojoBoy.

# Utilisation du sprite dans un programme

Comme pour tous les programmes destinés au DojoBoy, il faut commencer par importer le module DojoBoy.

from dojoboy_v1 import DojoBoy

Puis instancier un objet « DojoBoy » avec la variable djb .

djb = DojoBoy(False)

Le paramètre False va permettre d’éviter d’afficher l’écran de démarrage de la console.

Le sprite doit ensuite être importé dans le ‘catalogue’ des sprites avec la commande :

djb.display.add_sprite_from_file("MonSprite.bin", 16, 16)

Cette commande va lire le fichier ‘MonSprite.bin’ et l’intégrer au catalogue en prenant en compte sa taille (16x16 pixels).

Il sera ensuite possible d’afficher le sprite et de le faire déplacer à l’écran avec le code suivant :

for x in range (0,162,2):

djb.display.fill(djb.display.CYAN_H)

djb.display.sprite(0, x, 64)

djb.display.show()

La commande djb.display.sprite permet l’affichage du sprite à la position x,64. Le premier paramètre (ici 0 car il n’y a qu’un sprite) est l’index (la position) du sprite dans le catalogue.

# La couleur ‘transparente’ du sprite

En exécutant le code précédent, tu as probablement constaté un problème….

Si comme dans l’exemple tu as laissé le contour de ton sprite en blanc, ce contour blanc est aussi affiché 🤔

Heureusement, il existe une solution pour ne pas l’afficher et que la couleur blanche du sprite soit transparente. 😉

Remplace la commande djb.display.sprite par la suivante :

djb.display.sprite(0, x, 64, djb.display.WHITE_H)

Le dernier paramètre permet de définir la couleur du sprite qui doit être transparente (ici, blanc).

Challenge

- Crée d’autres sprites.
- Affiche-les à l’écran en les mettant en mouvement (chute, monter, descendre ,….)

# Infos générales

Auteur : CoderdojoBelgium - Date de publication : 03-2024 - CC-BY-NC-SA (http://creativecommons.org/licenses/by-nc-sa/3.0/)

Site web : www.coderdojobelgium.be - Contact : info@coderdojobelgium.be

ABOVE ALL, BE COOL!

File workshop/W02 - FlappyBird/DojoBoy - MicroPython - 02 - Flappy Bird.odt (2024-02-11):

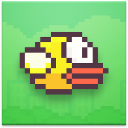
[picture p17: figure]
Flappy Bird - Wikipedia

2 - DojoBoy – Flappy Bird

Cet atelier a pour objectif de coder le jeu Flappy Bird en MicroPython (Python) sur la console DojoBoy.

Pour comprendre les étapes de cet atelier, il est préférable de maitriser les points aborder dans l’atelier DojoBoy N°1.

Le code dans ces pages n’est pas complet. Il est indispensable de suivre les étapes l’une après l’autre pour à l’objectif. Fais-toi aider des coachs si tu es perdu ou que tu ne comprends pas !

Les challenge en fin d’étapes vont te permette d’expérimenter ton code et de mieux le comprendre. Ne les passe pas trop vite… 😉

# Initialisation du DojoBoy

Comme pour tous les programmes destinés au DojoBoy, il faut commencer par importer le module DojoBoy.

from dojoboy_v1 import DojoBoy

Puis instancier un objet « DojoBoy » avec la variable djb .

djb = DojoBoy(False)

Le paramètre False va permettre d’éviter d’afficher l’écran de démarrage de la console.

Maintenant, commençons à coder le jeu ! 👍

Remarque : Il n’est pas nécessaire d’écrire le texte après le caractère # 😉

# Etape 1 : Flappy Bird = Rectangle...

Après avoir instancié la classe DojoBoy avec la variable djb, commençons par définir les bases du programme.

Pour cette première étape Flappy Bird prendra la forme d’un simple rectangle que nous allons déplacer verticalement avec le joystick.

Ecris le code suivant après djb = DojoBoy(False)

pos_x = 50

pos_y = 50

velocity_y = 2 # vitesse de deplacement

Ces variables sont utilisées pour définir la position de Flappy Bird à l’écran ainsi que le nombre de pixels verticaux dont se déplacera Flappy Bird lors de l’utilisation du joystick.

while True:

djb.display.fill(djb.display.BLACK) # remplir l'ecran en noir

djb.scan_jst_btn() # scan si joystick ou boutons appuyés

if djb.pressed(djb.btn_Up): # si joystick haut

pos_y = pos_y - velocity_y # reduit la valeur de pos_y

if djb.pressed(djb.btn_Down): # si joystick bas

pos_y = pos_y + velocity_y # augmente la valeur de pos_y

djb.display.rect(pos_x, int(pos_y), 19, 14, djb.display.YELLOW_H, True) # dessine un rectangle a la position pos_x , pos_y

djb.display.show_and_wait() # affiche l'ecran a 30 image par seconde

Le bloc de code commençant par la commande while défini la boucle principale du programme.

La fonction de chacune des lignes est décrite dans le commentaire après le caractère #.

Challenge

- Change la vitesse de déplacement de Flappy Bird
- Change le déplacement vertical par un déplacement horizontal

# Etape 2 : La chute de Flappy Bird

Avec le code de l’étape 1, Flappy Bird ne vole pas et n’est pas attiré par le sol. Il faut corriger ce comportement pour que lors de l’appui du bouton A, Flappy Bird se déplace vers le haut. En cas d’arrêt de l’appuis sur le bouton A, Flappy Bird tombera vers le sol.

Commençons par ajouter de nouvelles variables qui vont définir la vitesse de déplacement vers le haut et l’accélération (l’augmentation de la vitesse) lors de la chute.

Remarque : Ces variables ne changeront pas lors de l’exécution du programme. Ce sont des « constantes ». Pour les différencier des variables nous les définissons avec des majuscules 😉

VELOCITY_Y_UP = -2.4 # vers le haut il faut “reduire” la position Y

ACCELERATION_Y = 0.2 # difference de Vitesse a chaque execution de la boucle

Il faut ensuite modifier la gestion des boutons avec le code suivant dans la boucle principale.

if djb.pressed(djb.btn_A): # si bouton A appuyé

velocity_y = VELOCITY_Y_UP

pos_y = pos_y + velocity_y # reduit la valeur de pos_y

velocity_y = velocity_y + ACCELERATION_Y #modifie la vitesse

pos_y = pos_y + velocity_y # augmente la valeur de pos_y

Il n’est maintenant plus nécessaire de gérer les directions « haut » et « bas » du joystick (il n’y a plus que le bouton A pour faire monter Flappy Bird ). Le code pour la direction « bas » doit donc être remplacé par les commandes pour augmenter la vitesse de chute et déplacer vers le bas Flappy Bird.

Le reste du code est identique.

Challenge

- Modifie la vitesse de déplacement vers le haut et examine le nouveau comportement
- Modifie la vitesse de la chute et examine le nouveau comportement
- Ajoute le code pour éviter que Flappy Bird disparaisse sous le sol.

# Etape 3 : Les obstacles arrivent…

Flappy Bird est maintenant capable de voler…. Il est maintenant temps d’ajouter des obstacles…😁

L’obstacle (tuyau) prendra la forme d’un rectangle qui se déplace vers Flappy Bird.

Il faut donc ajouter des variables pour définir la position du tuyau (« pipe » en anglais) et sa vitesse de déplacement vers Flappy Bird.

VELOCITY_PIPE_X = -2 # vitesse de déplacement vers la gauche

pipe_pos_x = djb.display.width # place le tuyau au dela du bord droit de l’ecran

pipe_pos_y = 80 # le dessus du tuyau est à la position 80

Il faut ensuite faire bouger le tuyau vers la gauche, l’afficher à l’écran puis lorsqu’il arrive au-delà du bord gauche le faire disparaitre.

pipe_pos_x = pipe_pos_x + VELOCITY_PIPE_X # déplace le tuyau vers la gauche

if pipe_pos_x < -26: # si le tuyau est au-dela du bord gauche (0)

pipe_pos_x = djb.display.width #fais le apparaitre de nouveau au -dela du bord droit

djb.display.rect(pipe_pos_x,pipe_pos_y, 26, 100, djb.display.RED_H, True)

Solution : Vérifie si ton code pour éviter la chute de Flappy Bird au-delà du sol correspond à celui-ci :

if pos_y > djb.display.height - 14:

pos_y = djb.display.height - 14

Challenge

- Modifie les valeurs -14 et -26 dans le code. Examine le comportement avec ces changements.
- Modifie la vitesse de déplacement du tuyau.
- Modifie la hauteur du tuyau

# Etape 4 : En haut…en bas...

Le jeu est un peu monotone avec toujours la même hauteur de tuyau (et puis on peut toujours passer à travers le tuyau 😉). Ajoutons le code pour définir aléatoirement la hauteur du tuyau.

Comme tu as pu le vérifier, la hauteur du tuyau dépend de la valeur de la variable pipe_pos_y

Il faudrait donc que lorsque le tuyau disparait à gauche de l’écran, on définisse aléatoirement sa hauteur. Pour cela, il est nécessaire d’ajouter des commandes en ajoutant un module avec la ligne de code suivante en début de programme :

from random import randint

Il faut ensuite modifier le code qui fait ré apparaitre le tuyau sur le côté droit.

if pipe_pos_x < -26:

pipe_pos_x = djb.display.width

pipe_pos_y = randint(30, djb.display.height)

La commande randint permet de définir un nombre au hasard entre deux nombres (ici 30 et le bord du bas de l’écran 128). Ce nombre est ensuite assignée à la variable pipe_pos_y.

Challenge

- Modifie l’intervalle du nombre tiré au hasard pour la hauteur du tuyau. Examine le comportement.

# Etape 5 : Ouch… c’est dur ce truc…

Jusqu’à présent Flappy Bird pouvait voler sans obstacle en passant au travers du tuyau. Il est temps de corriger la chose…

Nous allons ajouter une méthode qui va vérifier si Flappy Bird rentre en contact avec le tuyau. Sur base des coordonnées de position x et y et des dimensions w (largeur) et h (hauteur) de Flappy Bird et du tuyau, la méthode va retourner la valeur True s’ils se touchent ou False dans le cas contraire.

Le code de la méthode doit être placé juste après la définition de la variable djb.

def check_collision(x1,y1,w1,h1,x2,y2,w2,h2):

return x1 + w1 >= x2 and x1 <= x2 + w2 and y1 + h1 >= y2 and y1 <= y2 + h2

Après la définition de la méthode check_collision , il faut maintenant l’utiliser dans note programme.

Pour l’utiliser, nous allons d’abord définir une nouvelle variable (à placer avec les autres) qui va être utilisée pour déterminer si le jeu continue ou s’arrête lorsque Flappy Bird touche le tuyau.

game_over = False

Ajoute le code suivant dans la boucle principale pour vérifier s’il y a une collision.

if check_collision(pos_x, pos_y, 19, 14, pipe_pos_x, pipe_pos_y, 26, 100):

game_over = True

En cas de collision la variable game_over est mise à la valeur True. Il faut ensuite arrêter le jeu avec le code suivant que l’on placera à la fin du code de la boucle principale.

if game_over:

djb.display.center_text("GAME OVER",djb.display.WHITE_H)

djb.display.show()

break

La commande break va permettre de sortir de la boucle principale et d’arrêter le jeu.

Challenge

- Modifie les valeurs 19,14, 26, 100. Examine maintenant le comportement du programme lors de collision.

# Etape 6 : Trop facile…

Flappy Bird a trop facile d’éviter l’unique tuyau. Il faut maintenant ajouter un nouveau tuyau au-dessus de celui du bas ! Avant d’ajouter le code pour cela, nous allons ajouter de nouvelles constantes et méthode pour améliorer la lecture du programme.

Ces constantes définissent la taille des tuyaux ainsi que la taille de l’espace entre le tuyau du et du bas.

PIPE_HOLE_SIZE = 40

PIPE_W = 26

PIPE_H = 100

Pour permettre l’ajout du nouveau tuyau, adapte la valeur de la variable

pipe_pos_y = -80

Pour simplifier l’affichage du nouveau tuyau, ajoute la méthode draw_pipe après la méthode check_collision .

def draw_pipe(p_x, p_y):

djb.display.rect(p_x,p_y, PIPE_W, PIPE_H, djb.display.RED_H, True)

djb.display.rect(p_x,p_y + PIPE_H + PIPE_HOLE_SIZE, PIPE_W, PIPE_H, djb.display.RED_L, True)

Il faut ensuite supprimer du programme le code qui permettait précédemment l’affichage de l’unique tuyau pour le remplacer par :

draw_pipe(pipe_pos_x, pipe_pos_y)

La vérification de la collision avec le tuyau doit aussi être modifiée avec ce code :

if check_collision(pos_x, pos_y, 19, 14, pipe_pos_x, pipe_pos_y, PIPE_W, PIPE_H):

game_over = True

if check_collision(pos_x, pos_y, 19, 14, pipe_pos_x, pipe_pos_y + PIPE_H + PIPE_HOLE_SIZE, PIPE_W, PIPE_H):

game_over = True

Challenge

- Adapte le code pour diminuer ou augmenter la taille de l’espace verticale entre les tuyaux.
- Adapte le code pour diminuer ou augmenter la vitesse de déplacement des tuyaux.

# Etape 7 : Encore trop facile…

Une seule paire de tuyau, c’est encore trop facile…. Ajoutons une nouvelle paire derrière la première.

Pour éviter la répétition de lignes de code identiques, nous allons encore ajouter de nouvelles méthodes.

La première va permettre de définir facilement la position d’une nouvelle paire de tuyau.

def create_pipe():

pos_x_p = djb.display.width

pos_y_p = randint(-PIPE_H,-PIPE_H + djb.display.height//2)

return pos_x_p, pos_y_p

La seconde simplifiera la détection de collision avec les tuyaux :

def check_pipe_collision(p_x, p_y, p_p_x, p_p_y):

g_over = False

if check_collision(p_x, p_y, 19, 14, p_p_x, p_p_y, PIPE_W, PIPE_H):

g_over = True

if check_collision(p_x, p_y, 19, 14, p_p_x, p_p_y + PIPE_H + PIPE_HOLE_SIZE, PIPE_W, PIPE_H):

g_over = True

return g_over

Elles sont à placer dans le programme avec les autres.

Pour gérer la nouvelle paire de tuyau, la définition des variables de position doivent être remplacées par celles-ci :

pipe_1_pos_x, pipe_1_pos_y = create_pipe()

pipe_2_pos_x, pipe_2_pos_y = create_pipe()

pipe_2_pos_x = pipe_2_pos_x + (djb.display.width + 19)//2

Dans la boucle principale, les ligne de code suivantes doivent être remplacée :

pipe_pos_x = pipe_pos_x + VELOCITY_PIPE_X

if pipe_pos_x < -26:

pipe_pos_x = djb.display.width

pipe_pos_y = randint(-PIPE_H,-PIPE_H + djb.display.height//2)

if check_collision(pos_x, pos_y, 19, 14, pipe_pos_x, pipe_pos_y, PIPE_W, PIPE_H):

game_over = True

if check_collision(pos_x, pos_y, 19, 14, pipe_pos_x, pipe_pos_y + PIPE_H + PIPE_HOLE_SIZE, PIPE_W, PIPE_H):

game_over = True

draw_pipe(pipe_pos_x, pipe_pos_y)

Par ces lignes de code :

pipe_1_pos_x = pipe_1_pos_x + VELOCITY_PIPE_X

pipe_2_pos_x = pipe_2_pos_x + VELOCITY_PIPE_X

if pipe_1_pos_x < -PIPE_W:

pipe_1_pos_x, pipe_1_pos_y = create_pipe()

if pipe_2_pos_x < -PIPE_W:

pipe_2_pos_x, pipe_2_pos_y = create_pipe()

draw_pipe(pipe_1_pos_x, pipe_1_pos_y)

draw_pipe(pipe_2_pos_x, pipe_2_pos_y)

if check_pipe_collision(pos_x, pos_y, pipe_1_pos_x, pipe_1_pos_y):

game_over = True

if check_pipe_collision(pos_x, pos_y, pipe_2_pos_x, pipe_2_pos_y):

game_over = True

Challenge

- Fais une pause et amuse toi un peu 😉

# Etape 8 : Flappy Bird met son costume…

Nous avons la base du jeu qui fonctionne mais le jeu est laid ! Il est temps de mettre de la couleur et de remplacer le bloc jaune qui représente Flappy Bird par une belle image…

Les images qui sont affichées dans les jeux d’appellent des sprites. Les sprites sont des images que l’on peut créer à partir d’images comme celles-ci.

Pour transformer Flappy Bird, ajoute ces lignes de code après la définition de la variable djb.

djb.display.add_sprite_from_file("flappy1.bin", 19, 14)

ALPHA_COLOR = djb.display.color(0,0,0)

Ces lignes ajoutent un sprite à l’image de Flappy Bird sur base du fichier « flappy1.bin » qui est doit déjà être présent dans la racine de la console.

Pour remplacer l’affichage du rectangle jaune, ajoute la ligne

djb.display.sprite(0, int(pos_x), int(pos_y), ALPHA_COLOR)

et supprime

djb.display.rect(pos_x, int(pos_y), 19, 14, djb.display.YELLOW_H, True)

# Etape 9 : On ajoute de beaux tuyaux...

Pour terminer, ajoutons des sprites pour les tuyaux.

Ajoute ces lignes en dessous de celle ajoutée pour Flappy Bird

djb.display.add_sprite_from_file("pipedown.bin", 26, 100)

djb.display.add_sprite_from_file("pipeup.bin", 26, 100)

Il faut ensuite modifier la méthode qui affiche les tuyaux draw_pipe en supprimant les lignes qui affichent les rectangles avec celles-ci :

djb.display.sprite(1, p_x, p_y, ALPHA_COLOR)

djb.display.sprite(2, p_x, p_y+ PIPE_H + PIPE_HOLE_SIZE, ALPHA_COLOR)

Le jeu est maintenant complet mais il peut encore être amélioré…

Challenge

- Change le fond de l’image noir avec du bleu ciel (djb.display.color(112,197,206))
- Ajoute un score ou les points sont obtenus après le passage d’une paire de tuyau par Flappy Bird.
- Ajout un sol qui défilent (SPRITE)
- Ajoute des objets bonus (SPRITE)

# Infos générales

Auteur : CoderdojoBelgium - Date de publication : 01-2024 - CC-BY-NC-SA (http://creativecommons.org/licenses/by-nc-sa/3.0/)

Site web : www.coderdojobelgium.be - Contact : info@coderdojobelgium.be

ABOVE ALL, BE COOL!

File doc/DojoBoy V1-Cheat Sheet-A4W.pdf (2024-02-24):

## Display

djb.display.fill(color)Ê:ÊfillÊdisplayÊwithÊcolor
Pixel and Lines (nave methods): djb.display.pixel(x,y[,color])Ê:ÊdrawÊpixelÊatÊx,ÊyÊusingÊtheÊgivenÊcolor djb.display.line(x1,y1,x2,y2,color)Ê:ÊdrawÊlineÊfromÊx1,y1ÊtoÊx2,y2ÊusingÊtheÊgivenÊcolor djb.display.vline(x,y,h,color)Ê:ÊdrawÊvercalÊlineÊatÊx,yÊwithÊhÊlenghtÊusingÊtheÊgivenÊcolor djb.display.hline(x,y,w,color)Ê:ÊdrawÊhorizontalÊlineÊatÊx,yÊwithÊwÊlengthÊusingÊtheÊgivenÊcolor Shapes (nave methods):
djb.display.rect(x,y,w,h,color[,fill])Ê:ÊdrawÊrectangleÊatÊx,yÊwithÊsizeÊw,hÊusingÊtheÊgivenÊcolor.Ê PassÊ‘True’ÊasÊlastÊparameterÊtoÊfillÊrectangle. djb.display.ellipse(x,y,rx,ry,color[,fill])Ê:ÊdrawÊellipseÊatÊx,yÊwithÊrxÊasÊvercalÊradiusÊandÊryÊasÊ horizontalÊradiusÊ(ÊrxÊ=ÊryÊforÊcircle)ÊusingÊtheÊgivenÊcolor.ÊPassÊ‘True’ÊasÊlastÊparameterÊtoÊfillÊ ellipse.
djb.display.poly(x,y,coords,color[,fill])Ê:ÊdrawÊpolygonÊatÊx,yÊwithÊarrayÊofÊrelaveÊcoordonatesÊ toÊx,yÊ(ex:array('h',[x0,y0,x1,y1,...xn,yn])ÊusingÊtheÊgivenÊcolor.ÊPassÊ‘True’ÊasÊlastÊparameterÊtoÊ fillÊpolygon.
djb.display.circle(x,y,rad,color[,fill])Ê:ÊdrawÊcircleÊatÊx,yÊwithÊradÊasÊradiusÊusingÊtheÊgivenÊcolor.Ê PassÊ‘True’ÊasÊlastÊparameterÊtoÊfillÊcircle. djb.display.triangle(x0,y0,x1,y1,x2,y2,color[,fill])Ê:ÊdrawÊtriangleÊaroundÊthreeÊpointsÊatÊ x0,y0,x1,y1,x2,y2ÊusingÊtheÊgivenÊcolor.ÊPassÊ‘True’ÊasÊlastÊparameterÊtoÊfillÊtriangle.
Text :
djb.display.text(string,Êx,Êy,Êcolor[,Êscale=1])Ê:ÊdrawÊtextÊatÊx,yÊusingÊtheÊgivenÊcolor.ÊSetÊscaleÊtoÊ 2ÊorÊ4ÊtoÊscaleÊupÊtext.
djb.display.center_text(string,Êcolor[,Êscale=1])Ê:ÊdrawÊtextÊatÊcenterÊofÊscreenÊusingÊtheÊgivenÊ color.ÊSetÊscaleÊtoÊ2ÊorÊ4ÊtoÊscaleÊupÊtext. djb.display.center_text_XY(string[,x],[y,]Êcolor[,Êscale=1])Ê:ÊdrawÊtextÊatÊvercalÊorÊhorizontalÊ centerÊofÊscreenÊusingÊtheÊgivenÊcolor.ÊSetÊscaleÊtoÊ2ÊorÊ4ÊtoÊscaleÊupÊtext.
Refresh display:
djb.display.show()Ê:ÊshowÊdisplay. djb.display.show_and_wait()Ê:ÊshowÊandÊrefreshÊdisplayÊatÊdefinedÊframerateÊ(defaultÊatÊ30Ê img/s).

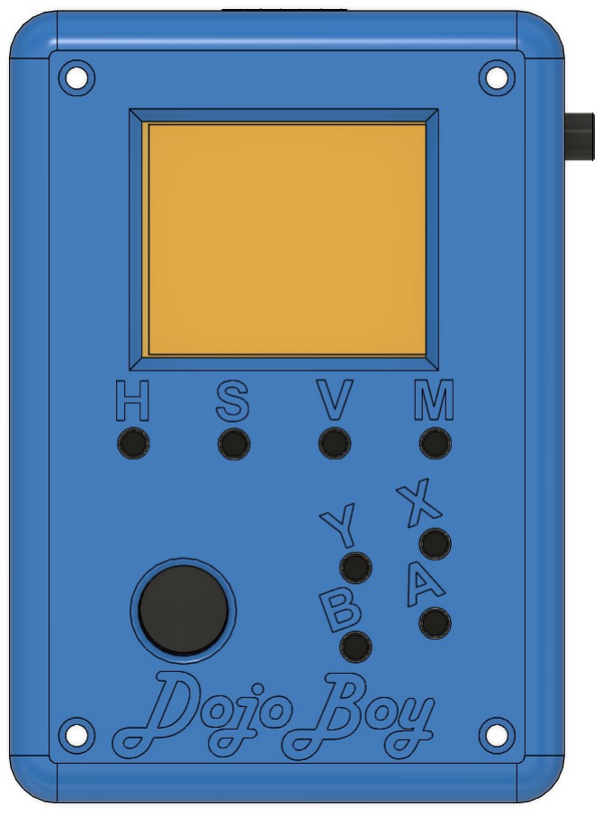
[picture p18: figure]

# CHEAT

# SHEET

## Class instance & init

djbÊ=ÊDojoBoy([show_intro=True][,Êwidth=xxx,Êheight=yyy][,Êframerate=30][,ÊrefreshBeep=5]) widthÊandÊheightÊdefineÊscreenÊresoluon.

## Import

fromÊdojoboy_v1.dojoboyÊimportÊDojoBoy

# DojoBoy Class

## Constants

Color:
djb.display.BLACK_H orÊBLACK:Êblack | djb.display.RED_LÊ:ÊdarkÊredÊÊÊÊÊÊÊÊÊÊÊÊÊÊÊÊ
djb.display.BLACK_L : darkÊgrey | djb.display.YELLOW_HÊ:Êbright yellow
djb.display.WHITE_HÊorÊWHITE: brightÊwhite | djb.display.YELLOW_LÊ:ÊdarkÊyellow
djb.display.WHITE_LÊ:ÊbrightÊgrey | djb.display.GREEN_HÊ:Êbright green
djb.display.BLUE_HÊ:ÊbrightÊnavyÊblue | djb.display.GREEN_LÊ:Êdark green
djb.display.BLUE_LÊ:ÊdarkÊnavyÊblueÊÊÊÊÊÊÊÊÊÊÊÊÊÊÊÊÊÊÊÊÊÊÊÊdjb.display.color_pal[c]:ÊcÊcolorÊindexÊ0..15ÊÊÊ
djb.display.CYAN_HÊ:Êbright skyÊblueÊÊÊÊÊÊÊÊÊÊ | Display:
djb.display.CYAN_LÊ:ÊdarkÊskyÊblueÊÊÊÊÊÊÊÊÊÊÊÊÊÊ | djb.display.widthÊ:ÊwidthÊofÊdisplayÊ
djb.display.MAGENTA_HÊ:ÊbrightÊpurple | djb.display.heightÊ:ÊheightÊofÊdisplay
djb.display.MAGENTA_LÊ:ÊdarkÊpurple | Sound:
djb.display.RED_HÊ:ÊbrightÊred | djb.sound.toneÊ:ÊtoneÊC1,ÊC#1,…,D8,D#8

Version 1.0 - 17/02/24

## Joysck and Buons Control

Buon constants:
djb.btn_UpÊ | :ÊUpÊbuon | djb.btn_Down | :ÊDownÊbuon
djb.btn_LeÊ | :ÊLeÊbuon | djb.btn_Right | :ÊRightÊbuon
djb.btn_AÊ | :ÊAÊbuon | djb.btn_B | :ÊBÊbuon
djb.btn_XÊ | :ÊXÊbuon | djb.btn_Y | :ÊYÊbuon
djb.btn_Home | :ÊHomeÊbuon | djb.btn_Start | :ÊStartÊbuon
djb.btn_Volume | :ÊVolumeÊbuon | djb.btn_Menu | :ÊMenuÊbuon
Methods:
djb.scan_jst_btn()Ê:ÊpollÊjoysckÊandÊbuonsÊstatus djb.pressed(buon)Ê:ÊreturnÊ‘True’ÊifÊbuonÊpressed djb.just_pressed(buon)Ê:ÊreturnÊoneÊmeÊ‘True’ÊifÊbuonÊpressed djb.just_released(buon)Ê:ÊreturnÊoneÊmeÊ‘True’ÊifÊbuonÊreleased

# CHEAT

# SHEET DojoBoy Class

## Sprite

djb.display.add_sprite(buffer,Êw,Êh):ÊaddÊaÊspriteÊinÊspriteÊlist.ÊBufferÊmustÊbeÊinÊRGB565Êformat.ÊwÊandÊhÊareÊwidthÊandÊheightÊofÊspriteÊinÊpixel.ÊReturnÊtheÊindexÊofÊsprite. djb.display.add_sprite_from_file(filename,Êw,Êh[,format]):ÊaddÊaÊspriteÊinÊspriteÊlistÊfromÊfileÊinÊ RGB565Êformat.ÊwÊandÊhÊareÊwidthÊandÊheightÊofÊspriteÊinÊpixel.ÊReturnÊtheÊindexÊofÊsprite. djb.display.add_rect_sprite(w,Êh,Êcolor):ÊaddÊaÊrectangularÊspriteÊwithÊcolocÊinÊspriteÊlist.ÊwÊandÊ hÊareÊwidthÊandÊheightÊofÊrectangularÊspriteÊinÊpixel.ÊReturnÊtheÊindexÊofÊsprite. djb.display.sprite(n,Êx,Êy[,Êtransparent_color]):ÊdisplayÊsprintÊnÊatÊx,Êy.Êtransparent_colorÊifÊdefinedÊhideÊthisÊcolorÊinÊsprite.
djb.display.sprite_width(n):ÊreturnÊwidthÊofÊspriteÊn djb.display.prite_height(n):returnÊheightÊofÊspriteÊn

## Sound

djb.play_freq(freq,Êduraon):ÊplayÊnonÊblockingÊsoundÊatÊfreqÊHzÊforÊduraon djb.play_tone(tone,Êduraon]):ÊplayÊnonÊblockingÊtoneÊatÊtoneÊnoteÊforÊduraon djb.bequiet(channel):ÊsilenceÊchannelÊ0Ê(sound—tone)ÊorÊ1Ê(song) djb.mute(status):ÊdisableÊallÊsoundÊwithÊTrue djb.start_song(songBuf):ÊplayÊnonÊblockingÊsong djb.stop_song():ÊstopÊplayingÊsong

Version 1.0 - 17/02/24

## Views

On/Off Switch

Extension Port

SD Card Reader

Micro USB Programming & Charging Port

Fixing Points

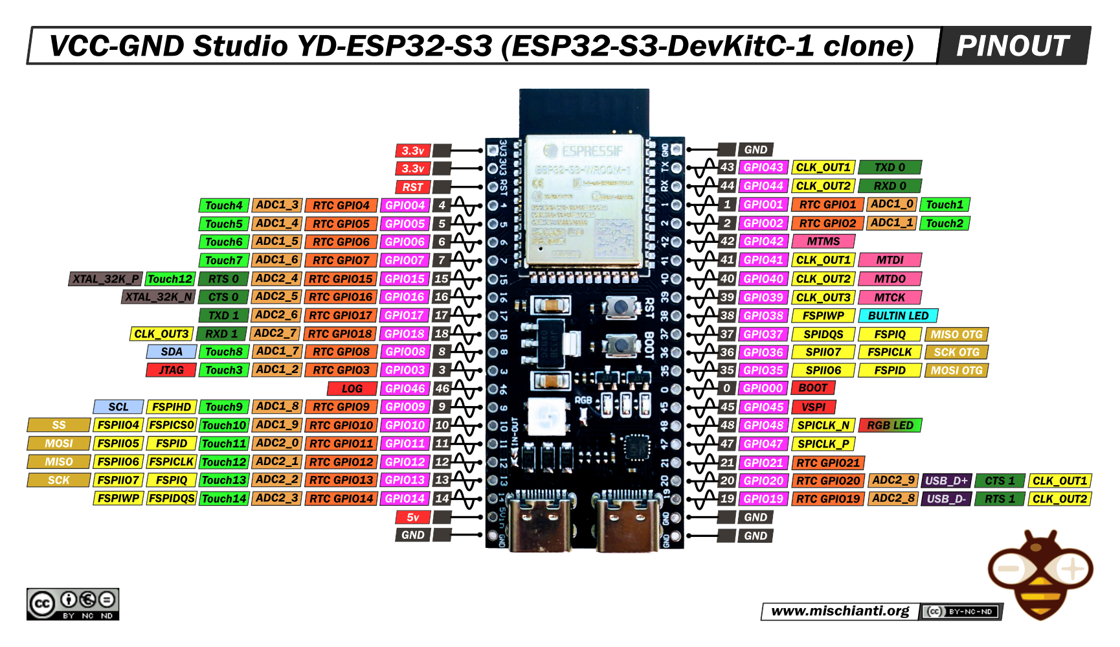
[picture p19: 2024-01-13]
doc/VCC-GND-Studio-YD-ESP32-S3-Devkitc-1-clone-Pinout.png

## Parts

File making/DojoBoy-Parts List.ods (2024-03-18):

DojoBoy Console |  |  |  |  | TOTAL Piece Lot |  | TOTAL |  | TOTAL
 |  |  |  |  | 111,15 € | DojoBoy Model A (PCBs) | 22,02 € | DojoBoy Model A (Univ PCBs) | 22,84 €
 |  | Lot/Qty | Prix | Livraison | Total | Qty | Prix/console | Qty | Prix/console
LCD TFT 1.8 ST7735 160x128 | Lien (https://fr.aliexpress.com/item/32947890530.html?curPageLogUid=ahfvNTeqsKwS) | 4 | 7,88 € | 1,57 € | 9,45 € | 1 | 2,36 € | 1 | 2,36 €
LCD IPS 1.54x1.54 ST7789 240x240 | Lien (https://fr.aliexpress.com/item/1005005556914555.html) | 1 | 2,62 € | 1,45 € | 4,07 € | 0 | 0,00 € | 0 | 0,00 €
RPI Pico W | Lien (https://www.kiwi-electronics.com/nl/raspberry-pi-boards-behuizingen-uitbreidingen-en-accessoires-59/raspberry-pi-pico-w-10938) | 1 | 7,95 € | 5,50 € | 13,45 € | 0 | 0,00 € | 0 | 0,00 €
RPI Pico | Lien (https://www.kiwi-electronics.com/nl/raspberry-pi-boards-behuizingen-uitbreidingen-en-accessoires-59/raspberry-pi-pico-10494) | 1 | 3,95 € | 5,50 € | 9,45 € | 0 | 0,00 € | 0 | 0,00 €
Clone RPI Pico (16MB) | Lien (https://fr.aliexpress.com/item/1005005495966620.html?mp=1) | 1 | 2,14 € | 1,28 € | 3,42 € | 1 | 3,42 € | 1 | 3,42 €
Switch 6x6x7.5 | Lien (https://fr.aliexpress.com/item/1005001629177989.html) | 100 | 0,87 € | 2,19 € | 3,06 € | 8 | 0,24 € | 8 | 0,24 €
Universal PCB 4x6cm | Lien (https://fr.aliexpress.com/item/1005001292089657.html) | 10 | 2,59 € | 1,51 € | 4,10 € | 0 | 0,00 € | 2 | 0,82 €
Speaker | Lien (https://fr.aliexpress.com/item/1005002504716932.html) | 10 | 10,49 € | 1,20 € | 11,69 € | 0 | 0,00 € | 0 | 0,00 €
Piezo 20mm | Lien (https://fr.aliexpress.com/item/1005001411342247.html?curPageLogUid=RGScjXC4jvUA) | 10 | 0,65 € | 1,57 € | 2,22 € | 1 | 0,22 € | 1 | 0,22 €
Battery Lipo Charger Buck Boost | Lien (https://fr.aliexpress.com/item/1005005133852642.html) | 10 | 8,01 € | 5,10 € | 13,11 € | 1 | 1,31 € | 1 | 1,31 €
Battery LiPo 3.7v 380mAh | Lien (https://fr.aliexpress.com/item/1005004246235415.html?curPageLogUid=zTNZiyWfV6Ow) | 1 | 4,83 € | 2,41 € | 7,24 € | 1 | 7,24 € | 1 | 7,24 €
PS2000 Joystick | Lien (https://fr.aliexpress.com/item/1005005231884808.html) | 4 | 5,07 € | 0,00 € | 5,07 € | 1 | 1,27 € | 1 | 1,27 €
Switch Souple 5x5 | Lien (https://fr.aliexpress.com/item/4001317887509.html) | 50 | 4,45 € | 1,49 € | 5,94 € | 0 | 0,00 € | 0 | 0,00 €
Switch Lock | Lien (https://fr.aliexpress.com/item/1005005616855013.html?curPageLogUid=8rklaLNqelZY) | 20 | 1,36 € | 1,83 € | 3,19 € | 1 | 0,16 € | 1 | 0,16 €
Visserie 30mm M2 ou M2.5 | Lien (https://fr.aliexpress.com/item/32810872544.html) | 50 | 2,77 € | 0,00 € | 2,77 € | 4 | 0,22 € | 4 | 0,22 €
Visserie 4mm M2 | Lien (https://fr.aliexpress.com/item/32810872544.html) | 50 | 0,79 € | 0,00 € | 0,79 € | 13 | 0,21 € | 13 | 0,21 €
Pin header Male | Lien (https://fr.aliexpress.com/item/1005005381259648.html) | 10 | 0,66 € | 1,91 € | 2,57 € | 2 | 0,51 € | 2 | 0,51 €
Pin Header Female | Lien (https://fr.aliexpress.com/item/1005005038036493.html?curPageLogUid=5qomIDOTbYs2) | 10 | 1,52 € | 0,68 € | 2,20 € | 2 | 0,44 € | 2 | 0,44 €
Cable Female-Female 10cm | Lien (https://fr.aliexpress.com/item/4000203371860.html) | 40 | 1,77 € | 0,59 € | 2,36 € | 30 | 1,77 € | 30 | 1,77 €
3D Print |  | 1 | 5,00 € | 0,00 € | 5,00 € | 1 | 5,00 € | 1 | 5,00 €
PCBs (JLCPCB) |  | 10 | 13,52 € | 0,00 € | 13,52 € | 1 | 1,35 € | 0 | 0,00 €

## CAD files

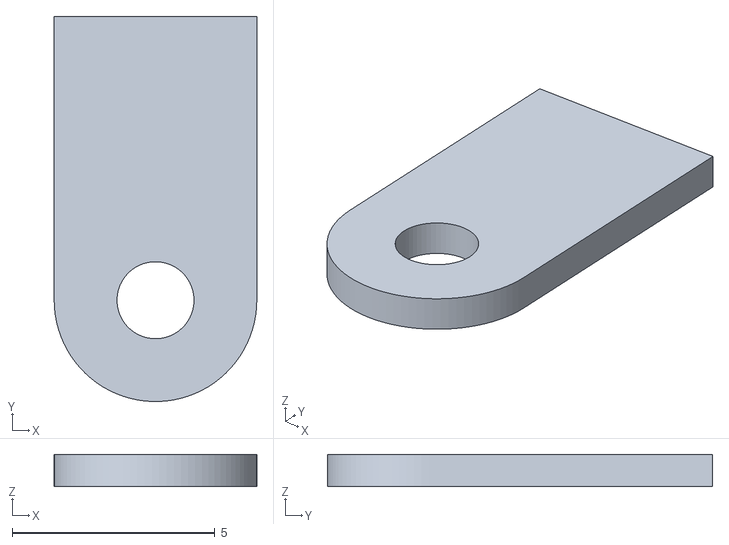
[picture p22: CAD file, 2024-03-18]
making/STL/DojoBoy-Model A-Support-Switch.stl
5.00 x 9.50 x 0.8

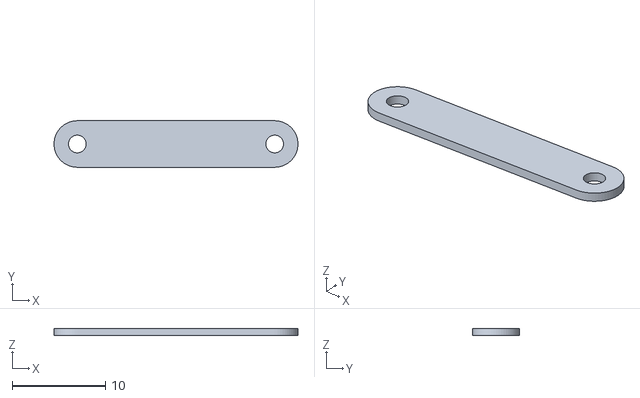
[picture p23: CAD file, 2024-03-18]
making/STL/DojoBoy-Model A-Support-Charger.stl
26.2 x 5.00 x 0.8

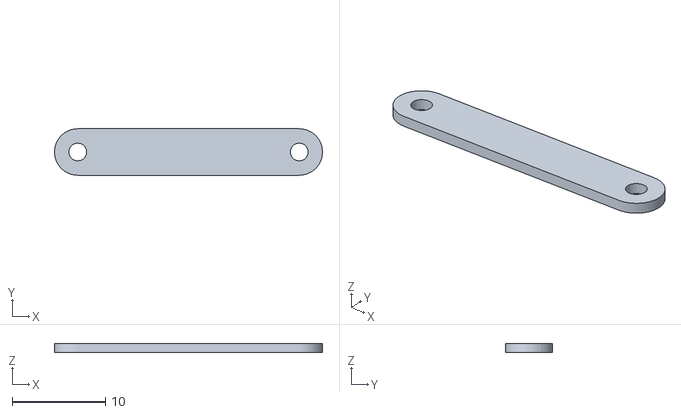
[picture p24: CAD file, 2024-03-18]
making/STL/DojoBoy-Model A-Support-Joystick.stl
28.8 x 5.00 x 1.00

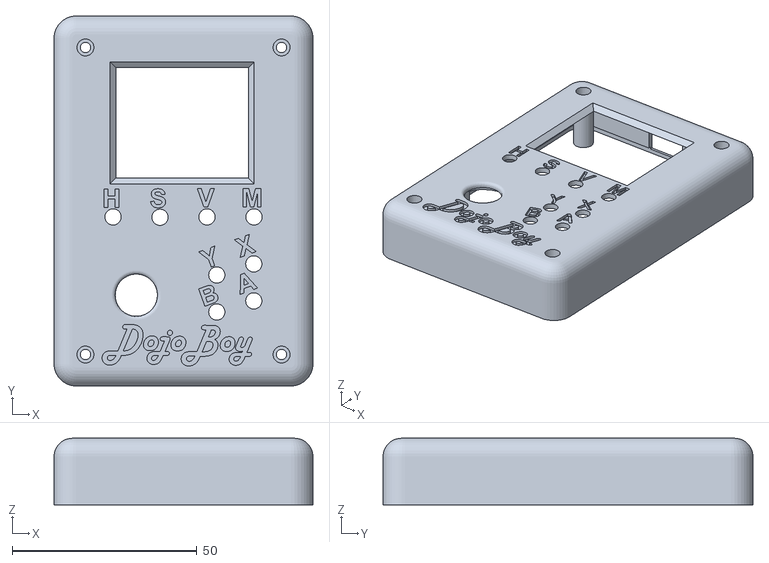
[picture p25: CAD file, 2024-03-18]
making/STL/DojoBoy-Model A-Top.stl
70.0 x 100.0 x 18.0

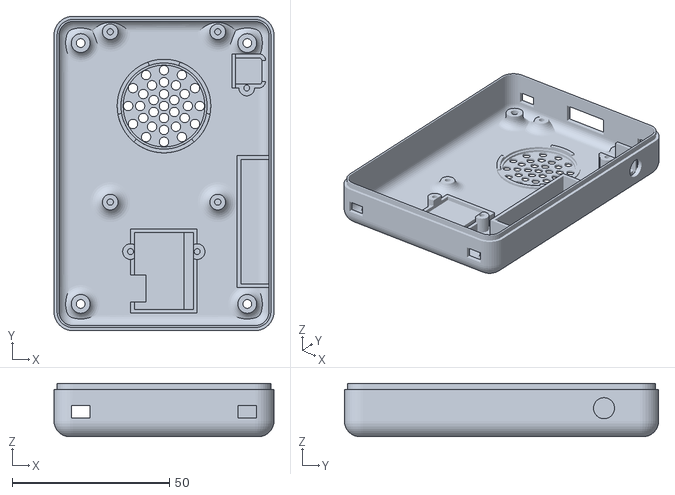
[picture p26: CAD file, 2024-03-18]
making/STL/DojoBoy-Model A-Bottom.stl
70.0 x 100.0 x 17.0

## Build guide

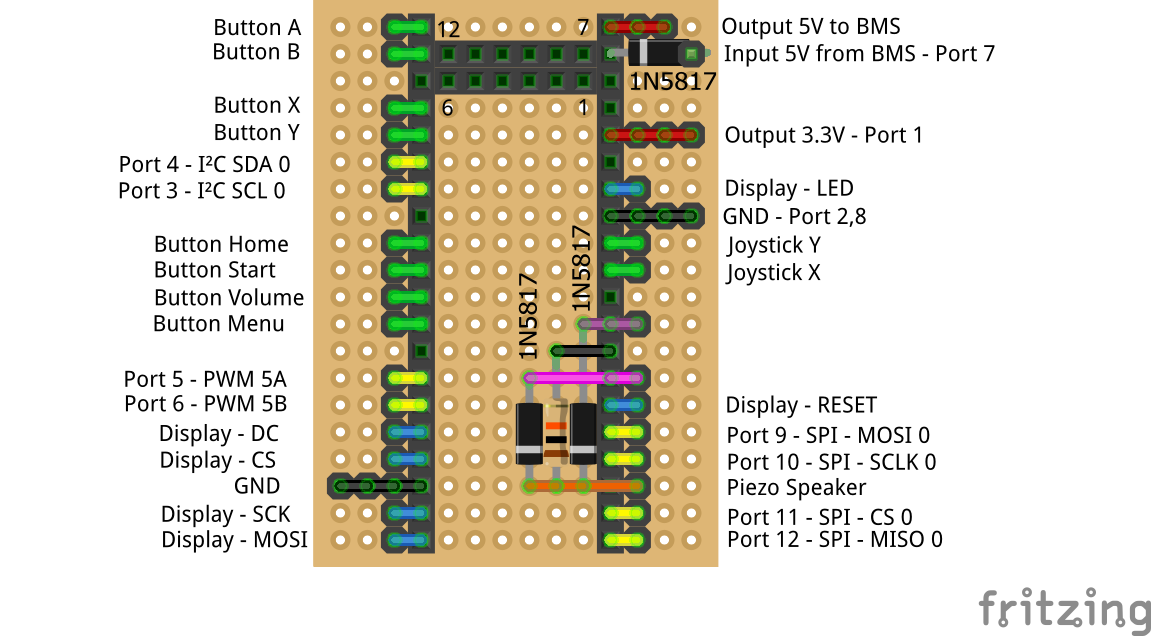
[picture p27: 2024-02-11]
making/DojoBoy-Board-V1_bb.png

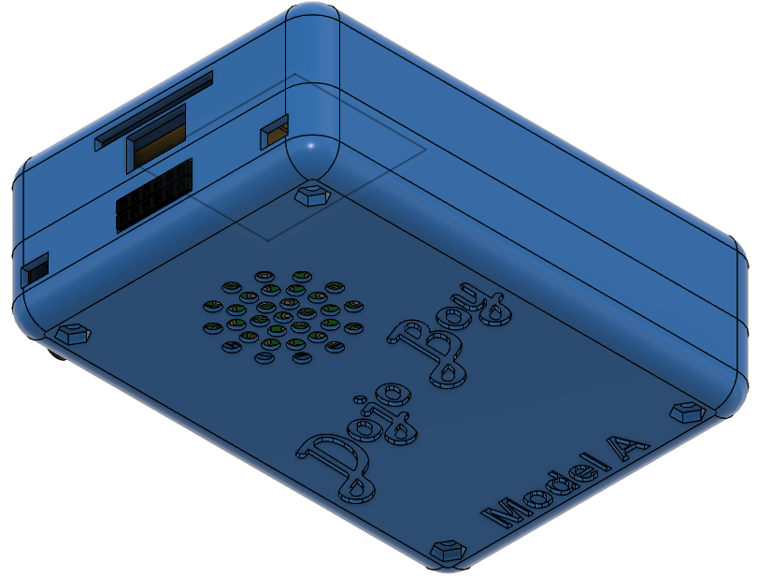
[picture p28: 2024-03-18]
making/DojoBoy-Model A-Back.PNG

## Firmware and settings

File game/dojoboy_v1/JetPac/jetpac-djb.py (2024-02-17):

 #
# ArduBoy Jet Pac
# Version 1.1
# 2nd Feb 2017
# by Mike McRoberts (a.k.a. TheArduinoGuy)
# MicroPython port for DojoBoy by Yoyo Zorglup 26 12 23
#

from time import sleep_ms,ticks_ms, ticks_us, ticks_diff
from random import randint
from dojoboy_v1 import DojoBoy
import machine

#machine.freq(240_000_000)

djb = DojoBoy(show_intro=True,width=128,height=64,framerate=60)

level = 1
gameDifficulty = 2
levelStep = 0
rocketStep = 0
monsterType = 0
gameState = 4
subState = 0
highScore = 0
lives = 4
score = 0

# fuel cells
fuelX = 0
fuelY = -8
fuelPercent = 0

# Jet man data
jetManX = 60
jetManY= 47
jetManXRate = 0
jetManYRate = 0
jetManDirection = 1
jetManState = 0

# rocket data
topRocketX = 0
topRocketY = 0
middleRocketX = 0
middleRocketY = 0
bottomRocketX = 0
bottomRocketY = 0

# data for the bonus items
bonusX = 0
bonusY = 0
bonusState = 0
bonusType = 0

cloudIndex = 0
jetPacFired = 0
buttonBPressed = False
animToggle = 0
frameRate = 0
lastPressed = 0

platforms = [2,4,3,7,5,2,11,3,3]
rocketParts = [24,24,60,32,76,55]


class movingObjects():
        x: float = 0
        y: float = 0
        xRate: float = 0
        yRate: float = 0
        direction: bool = True

monsters = []
for x in range (0,11):
    monsters.append(movingObjects())


#@dataclass
class cloudObjects:
        state: int = 0
        x: int = 0
        y: int = 0
        time: int = 0

clouds = []
for x in range (0,11):
    clouds.append(cloudObjects())

class laserObjects:
        x: int = 0
        y: int = 0
        length: int = 0
        direction: bool = True
        time: int = 0

laserbeams = []
for x in range (0,21):
    laserbeams.append(laserObjects())

laserIndex = 0

JETMANRIGHTHEAD = bytearray(b'\xF8\x70\x8C\xDE\xDA\x0A\x80\x00')
djb.display.add_sprite(JETMANRIGHTHEAD,8,8, 1) # Sprite 0
del JETMANRIGHTHEAD
JETMANLEFTHEAD = bytearray(b'\x00\x80\x0a\xda\xde\x8c\x70\xf8')
djb.display.add_sprite(JETMANLEFTHEAD,8,8, 1) # Sprite 1
del JETMANLEFTHEAD
JETMANRIGHT1 = bytearray(b'\x1F\x18\x06\xDD\xDD\x82\x03\x02')
djb.display.add_sprite(JETMANRIGHT1,8,8, 1) # Sprite 2
del JETMANRIGHT1
JETMANLEFT1 = bytearray(b'\x02\x03\x82\xdd\xdd\x06\x18\x1f')
djb.display.add_sprite(JETMANLEFT1,8,8, 1) # Sprite 3
del JETMANLEFT1
JETMANRIGHT2 = bytearray(b'\x1f\xd8\xe6\xbd\xfd\xc2\x83\x02')
djb.display.add_sprite(JETMANRIGHT2,8,8, 1) # Sprite 4
del JETMANRIGHT2
JETMANLEFT2 = bytearray(b'\x02\x83\xc2\xfd\xbd\xe6\xd8\x1f')
djb.display.add_sprite(JETMANLEFT2,8,8, 1) # Sprite 5
del JETMANLEFT2
JETMANRIGHT3 = bytearray(b'\x9f\xd8\xb6\x3d\x3d\xe2\xc3\x82')
djb.display.add_sprite(JETMANRIGHT3,8,8, 1) # Sprite 6
del JETMANRIGHT3
JETMANLEFT3 = bytearray(b'\x82\xc3\xe2\x3d\x3d\xb6\xd8\x9f')
djb.display.add_sprite(JETMANLEFT3,8,8, 1) # Sprite 7
del JETMANLEFT3
JETMANRIGHTFLY1 = bytearray(b'\x5f\x98\x46\x2d\x0d\x7e\x6f\x42')
djb.display.add_sprite(JETMANRIGHTFLY1,8,8, 1) # Sprite 8
del JETMANRIGHTFLY1
JETMANRIGHTFLY2 = bytearray(b'\x9f\x58\xa6\x4d\x0d\x7e\x6f\x42')
djb.display.add_sprite(JETMANRIGHTFLY2,8,8, 1) # Sprite 9
del JETMANRIGHTFLY2
JETMANRIGHTFLY3 = bytearray(b'\x5f\xb8\x46\xad\x0d\x7e\x6f\x42')
djb.display.add_sprite(JETMANRIGHTFLY3,8,8, 1) # Sprite 10
del JETMANRIGHTFLY3
JETMANLEFTFLY1 = bytearray(b'\x42\x6f\x7e\x0d\x2d\x46\x98\x5f')
djb.display.add_sprite(JETMANLEFTFLY1,8,8, 1) # Sprite 11
del JETMANLEFTFLY1
JETMANLEFTFLY2 = bytearray(b'\x42\x6f\x7e\x0d\x4d\xa6\x58\x9f')
djb.display.add_sprite(JETMANLEFTFLY2,8,8, 1) # Sprite 12
del JETMANLEFTFLY2
JETMANLEFTFLY3 = bytearray(b'\x42\x6f\x7e\x0d\xad\x46\xb8\x5f')
djb.display.add_sprite(JETMANLEFTFLY3,8,8, 1) # Sprite 13
del JETMANLEFTFLY3
PLATFORM = bytearray(b'\x06\x03\x0f\x0f\x07\x03\x0f\x06')
djb.display.add_sprite(PLATFORM,8,8, 1) # Sprite 14
del PLATFORM
BOTTOMROCKET = bytearray(b'\xFF\x1F\x64\x7B\x7B\x64\x1F\xFF')
djb.display.add_sprite(BOTTOMROCKET,8,8, 1) # Sprite 15
del BOTTOMROCKET
MIDDLEROCKET = bytearray(b'\xE0\xF0\x0F\xFF\xFF\x0F\xF0\xE0')
djb.display.add_sprite(MIDDLEROCKET,8,8, 1) # Sprite 16
del MIDDLEROCKET
TOPROCKET = bytearray(b'\x00\x00\x6E\x6F\x6F\x6E\x00\x00')
djb.display.add_sprite(TOPROCKET,8,8, 1) # Sprite 17
del TOPROCKET
TOPSHUTTLE = bytearray(b'\x00\x00\xf8\xd6\xff\xff\x02\xfc')
djb.display.add_sprite(TOPSHUTTLE,8,8, 1) # Sprite 18
del TOPSHUTTLE
MIDDLESHUTTLE = bytearray(b'\x00\x00\xff\x24\xdb\xff\x00\xff')
djb.display.add_sprite(MIDDLESHUTTLE,8,8, 1) # Sprite 19
del MIDDLESHUTTLE
BOTTOMSHUTTLE = bytearray(b'\xfc\x42\x3f\x1c\x0f\x7f\xf0\x0f')
djb.display.add_sprite(BOTTOMSHUTTLE,8,8, 1) # Sprite 20
del BOTTOMSHUTTLE
TOPFAT = bytearray(b'\x80\xf0\x88\xf7\xff\xf8\xf0\x80')
djb.display.add_sprite(TOPFAT,8,8, 1) # Sprite 21
del TOPFAT
MIDDLEFAT = bytearray(b'\xfa\x0d\xfa\xad\xfa\xfd\xfa\xff')
djb.display.add_sprite(MIDDLEFAT,8,8, 1) # Sprite 22
del MIDDLEFAT
BOTTOMFAT = bytearray(b'\xcf\xf0\xdf\x3a\x3f\xdf\xff\xcf')
djb.display.add_sprite(BOTTOMFAT,8,8, 1) # Sprite 23
del BOTTOMFAT
TOPFUTURE = bytearray(b'\xc0\xb0\x4c\xff\xff\x0c\x30\xc0')
djb.display.add_sprite(TOPFUTURE,8,8, 1) # Sprite 24
del TOPFUTURE
MIDDLEFUTURE = bytearray(b'\xe3\x8e\x39\xff\xff\x38\x8c\xe3')
djb.display.add_sprite(MIDDLEFUTURE,8,8, 1) # Sprite 25
del MIDDLEFUTURE
BOTTOMFUTURE = bytearray(b'\xff\x1f\x40\x7f\x7f\x40\x1f\xff')
djb.display.add_sprite(BOTTOMFUTURE,8,8, 1) # Sprite 26
del BOTTOMFUTURE
# BONUS ITEMS
FUEL = bytearray(b'\x7e\xFF\xC1\xF5\xF5\xFD\xFF\x7E')
djb.display.add_sprite(FUEL,8,8, 1) # Sprite 27
del FUEL
DIAMOND = bytearray(b'\x18\x34\x6e\xee\xee\x6e\x34\x18')
djb.display.add_sprite(DIAMOND,8,8, 1) # Sprite 28
del DIAMOND
BREAD = bytearray(b'\x70\xc8\xe4\xf4\xf4\xf4\xf8\x70')
djb.display.add_sprite(BREAD,8,8, 1) # Sprite 29
del BREAD
GOLD = bytearray(b'\x80\xe0\x98\x86\x9e\xf8\xe0\x80')
djb.display.add_sprite(GOLD,8,8, 1) # Sprite 30
del GOLD
ATOM = bytearray(b'\x60\xd0\xf6\x6d\x7f\xd6\xf0\x60')
djb.display.add_sprite(ATOM,8,8, 1) # Sprite 31
del ATOM
NUKE = bytearray(b'\xe0\xe0\xee\x0e\xee\xe0\xe0\x00')
djb.display.add_sprite(NUKE,8,8, 1) # Sprite 32
del NUKE
# MISC ITEMS
LITTLEMAN = bytearray(b'\x10\x88\xfe\x7d\x7d\xfe\x88\x10')
djb.display.add_sprite(LITTLEMAN,8,8, 1) # Sprite 33
del LITTLEMAN
THRUST1 = bytearray(b'\x14\x7e\xa8\x76\xdc\xb6\x5a\x14')
djb.display.add_sprite(THRUST1,8,8, 1) # Sprite 34
del THRUST1
THRUST2 = bytearray(b'\x0c\x3a\x56\xbc\x5a\xac\x36\x0c')
djb.display.add_sprite(THRUST2,8,8, 1) # Sprite 35
del THRUST2
CLOUD1 = bytearray(b'\x30\x6c\x74\xba\x6a\x7e\x4c\x30')
djb.display.add_sprite(CLOUD1,8,8, 1) # Sprite 36
del CLOUD1
CLOUD2 = bytearray(b'\x00\x00\x30\xd8\x68\xec\xf8\x5c\xdc\xe8\x7c\xd8\xf0\x20\x00\x00\x00\x00\x0b\x14\x3f\x29\x36\x17\x3b\x1f\x2f\x12\x1e\x0b\x00\x00')
djb.display.add_sprite(CLOUD2,16,16, 1) # Sprite 37
del CLOUD2
CLOUD3 = bytearray(b'\x00\x40\x62\x18\x6c\x18\x14\x08\x34\x0A\x54\xAC\x60\xB1\x00\x00\x02\x00\x45\x1A\x3D\x04\xAA\x04\x10\x29\x14\x2A\x16\x0D\x42\x10')
djb.display.add_sprite(CLOUD3,16,16, 1) # Sprite 38
del CLOUD3
# BADDIES
ASTEROIDRIGHT1 = bytearray(b'\x2A\x55\x3E\x77\x5d\x7b\x26\x1c')
djb.display.add_sprite(ASTEROIDRIGHT1,8,8, 1) # Sprite 39
del ASTEROIDRIGHT1
ASTEROIDRIGHT2 = bytearray(b'\x55\x2a\x3e\x77\x5d\x7b\x26\x1c')
djb.display.add_sprite(ASTEROIDRIGHT2,8,8, 1) # Sprite 40
del ASTEROIDRIGHT2
ASTEROIDLEFT1 = bytearray(b'\x1c,0x26,0x7b,0x5d,0x77,0x3e,0x55,0x2a')
djb.display.add_sprite(ASTEROIDLEFT1,8,8, 1) # Sprite 41
del ASTEROIDLEFT1
ASTEROIDLEFT2 = bytearray(b'\x1c,0x26,0x7b,0x5d,0x77,0x3e,0x2a,0x55')
djb.display.add_sprite(ASTEROIDLEFT2,8,8, 1) # Sprite 42
del ASTEROIDLEFT2
FUZZY1 = bytearray(b'\x3c\x76\xeb\x76\xf7\x6a\x36\x1c')
djb.display.add_sprite(FUZZY1,8,8, 1) # Sprite 43
del FUZZY1
FUZZY2 = bytearray(b'\x1c\x76\x6a\xf7\x76\xeb\x76\x3c')
djb.display.add_sprite(FUZZY2,8,8, 1) # Sprite 44
del FUZZY2
BALL1 = bytearray(b'\x3c\x72\xf9\xfd\xff\xff\x7e\x3c')
djb.display.add_sprite(BALL1,8,8, 1) # Sprite 45
del BALL1
BALL2 = bytearray(b'\x1c\x32\x79\x7d\x7f\x7f\x3e\x1c')
djb.display.add_sprite(BALL2,8,8, 1) # Sprite 46
del BALL2
PLANE1 = bytearray(b'\x1e\xbc\xb8\xf8\xf8\xa8\xb0\x20')
djb.display.add_sprite(PLANE1,8,8, 1) # Sprite 47
del PLANE1
PLANE2 = bytearray(b'\x20\xb0\xa8\xf8\xf8\xb8\xbc\x1e')
djb.display.add_sprite(PLANE2,8,8, 1) # Sprite 48
del PLANE2
CROSS = bytearray(b'\x10\x28\x7c\xaa\x7c\x28\x10\x00')
djb.display.add_sprite(CROSS,8,8, 1) # Sprite 49
del CROSS
FALCON1 = bytearray(b'\x99\xbd\x66\x66\x7e\x3c\x24\x24')
djb.display.add_sprite(FALCON1,8,8, 1) # Sprite 50
del FALCON1
FALCON2 = bytearray(b'\x24\x24\x3c\x7e\x66\x66\xbd\x99')
djb.display.add_sprite(FALCON2,8,8, 1) # Sprite 51
del FALCON2
UFO1 = bytearray(b'\x20\x50\xf8\xdc\xfc\xd8\x70\x20')
djb.display.add_sprite(UFO1,8,8, 1) # Sprite 52
del UFO1
UFO2 = bytearray(b'\x20\x70\xd8\xfc\xdc\xf8\x50\x20')
djb.display.add_sprite(UFO2,8,8, 1) # Sprite 53
del UFO2
JELLY = bytearray(b'\x6c\xfe\xb9\x7b\x7f\xb9\xfa\x6c')
djb.display.add_sprite(JELLY,8,8, 1) # Sprite 54
del JELLY
BLANK = bytearray(b'\x00\x00\x00\x00\x00\x00\x00\x00')
djb.display.add_sprite(BLANK,8,8, 1) # Sprite 55
del BLANK
LASER1 = bytearray(b'\x01\x01\x01\x01\x01\x01\x01\x01')
djb.display.add_sprite(LASER1,8,8, 1) # Sprite 56
del LASER1
LASER2 = bytearray(b'\x01\x01\x01\x01\x00\x00\x00\x00')
djb.display.add_sprite(LASER2,8,8, 1) # Sprite 57
del LASER2

################################

WHITE_H_PAL = djb.display.palette_mono(djb.display.WHITE_H, djb.display.BLACK)
BLUE_H_PAL = djb.display.palette_mono(djb.display.BLUE_H, djb.display.BLACK)
RED_H_PAL = djb.display.palette_mono(djb.display.RED_H, djb.display.BLACK)
GREEN_H_PAL = djb.display.palette_mono(djb.display.GREEN_H, djb.display.BLACK)
CYAN_H_PAL = djb.display.palette_mono(djb.display.CYAN_H, djb.display.BLACK)
MAGENTA_H_PAL = djb.display.palette_mono(djb.display.MAGENTA_H, djb.display.BLACK)
YELLOW_H_PAL = djb.display.palette_mono(djb.display.YELLOW_H, djb.display.BLACK)

################################

def RANDOMXL():
        return randint(-64,0)
    
def RANDOMXR():
        return randint(128,192)

def RANDOMY():
        return randint(48,56)

def RANDOMXRATE():
        return (0.15+(randint(0,90+(gameDifficulty*5))/100))

def RANDOMYRATE():
        return ((randint(0,40)/100)-0.2)

def FUELRANDOM():
        return (16+randint(0,48) if randint(0,1) else 88+randint(0,16))

#########################################
    
def initialiseGameState():
        global gameState, jetManX, jetManY,jetManDirection, jetManXRate, jetManYRate
        gameState = 1
        jetManX = 60
        jetManY = 47
        jetManDirection = 1 
        jetManXRate = 0
        jetManYRate = 0

        for index in range (0,9):
                clouds[cloudIndex].state = 0
                clouds[cloudIndex].x = 0
                clouds[cloudIndex].y = 0
                clouds[cloudIndex].time = 0
                
        for index in range (0,19):
                laserbeams[index].x = 0
                laserbeams[index].y = 0
                laserbeams[index].length = 0
                laserbeams[index].direction = 0
                laserbeams[index].time = 0

                
#=#=#=#=#=#=#=#=#=#=#=#=#=#=#=#=#=#=#=#=#=#=#=#=#=#=#=#=#=#=#=#=#=#=#=#=#=#=#=#=#=#=#=#=#=#=#=#=#=#=#=#=#=#=#=#=#=#=#=#=
def createMonsters():
        for index in range (0,9):
                DIRECTION = randint (0,1)
                monsters[index].x = (RANDOMXR() if DIRECTION else RANDOMXL())
                monsters[index].y = RANDOMY()
                monsters[index].xRate = RANDOMXRATE()
                monsters[index].yRate = RANDOMYRATE()
                monsters[index].directin = DIRECTION

#=#=#=#=#=#=#=#=#=#=#=#=#=#=#=#=#=#=#=#=#=#=#=#=#=#=#=#=#=#=#=#=#=#=#=#=#=#=#=#=#=#=#=#=#=#=#=#=#=#=#=#=#=#=#=#=#=#=#=#=
def initialiseRocket():
        global topRocketX,topRocketY,middleRocketX,middleRocketY,bottomRocketX,bottomRocketY, rocketParts
        topRocketX = rocketParts[0]
        topRocketY = rocketParts[1]
        middleRocketX = rocketParts[2]
        middleRocketY = rocketParts[3]
        bottomRocketX = rocketParts[4]
        bottomRocketY = rocketParts[5]

#=#=#=#=#=#=#=#=#=#=#=#=#=#=#=#=#=#=#=#=#=#=#=#=#=#=#=#=#=#=#=#=#=#=#=#=#=#=#=#=#=#=#=#=#=#=#=#=#=#=#=#=#=#=#=#=#=#=#=#=
def drawPlatforms():
        for index in range (0,9,3):
                length = platforms[index+2]
                for row in range (0,length):
                        platformX = platforms[index]
                        platformX = (platformX*8)+(row*8)
                        platformY = platforms[index+1]
                        platformY = platformY*8
                        djb.display.sprite(14, platformX, platformY,djb.display.BLACK,GREEN_H_PAL)

#=#=#=#=#=#=#=#=#=#=#=#=#=#=#=#=#=#=#=#=#=#=#=#=#=#=#=#=#=#=#=#=#=#=#=#=#=#=#=#=#=#=#=#=#=#=#=#=#=#=#=#=#=#=#=#=#=#=#=#=
def drawJetMan():
        global jetManX, jetManY, jetManDirection, animToggle, jetManState
        if jetManState == 0: # standing
                if jetManDirection:
                        djb.display.sprite(0, int(jetManX), int(jetManY),djb.display.BLACK,WHITE_H_PAL) # 0 JETMANRIGHTHEAD
                        if jetManXRate == 0:
                                djb.display.sprite(2, int(jetManX), int(jetManY)+8,djb.display.BLACK,WHITE_H_PAL) # 2 JETMANRIGHT1
                        else:
                                if animToggle == 0:
                                        djb.display.sprite(2, int(jetManX), int(jetManY)+8,djb.display.BLACK,WHITE_H_PAL) # 2 JETMANRIGHT1
                       
                                elif animToggle == 1:
                                        djb.display.sprite(4, int(jetManX), int(jetManY)+8,djb.display.BLACK,WHITE_H_PAL) # 4 JETMANRIGHT2
                             
                                elif animToggle == 2:
                                        djb.display.sprite(6, int(jetManX), int(jetManY)+8,djb.display.BLACK,WHITE_H_PAL) # 6 JETMANRIGHT3
                               
                                elif animToggle == 3:
                                        djb.display.sprite(4, int(jetManX), int(jetManY)+8,djb.display.BLACK,WHITE_H_PAL)
                                 
                else:
                        djb.display.sprite(1, int(jetManX), int(jetManY),djb.display.BLACK,WHITE_H_PAL) # 1 JETMANLEFTHEAD
                        if jetManXRate == 0:
                                djb.display.sprite(3, int(jetManX), int(jetManY)+8,djb.display.BLACK,WHITE_H_PAL) # 3 JETMANLEFT1
                        else:
                                if animToggle == 0:
                                        djb.display.sprite(3, int(jetManX), int(jetManY)+8,djb.display.BLACK,WHITE_H_PAL)
                            
                                elif animToggle == 1:
                                        djb.display.sprite(5, int(jetManX), int(jetManY)+8,djb.display.BLACK,WHITE_H_PAL) # 5 JETMANLEFT2
                         
                                elif animToggle == 2:
                                        djb.display.sprite(7, int(jetManX), int(jetManY)+8,djb.display.BLACK,WHITE_H_PAL) # 7 JETMANLEFT3
                         
                                elif animToggle == 3:
                                        djb.display.sprite(5, int(jetManX), int(jetManY)+8,djb.display.BLACK,WHITE_H_PAL)
                         

        if jetManState == 1 or jetManState==2: # Rising or falling
                if jetManDirection:
                        djb.display.sprite(0, int(jetManX), int(jetManY),djb.display.BLACK,WHITE_H_PAL)
                        
                        if animToggle == 0:
                                djb.display.sprite(8, int(jetManX), int(jetManY)+8,djb.display.BLACK,WHITE_H_PAL) # 8 JETMANRIGHTFLY1
                     
                        elif animToggle == 1:
                                djb.display.sprite(9, int(jetManX), int(jetManY)+8,djb.display.BLACK,WHITE_H_PAL) # 9 JETMANRIGHTFLY2
               
                        elif animToggle == 2:
                                djb.display.sprite(10, int(jetManX), int(jetManY)+8,djb.display.BLACK,WHITE_H_PAL) # 10 JETMANRIGHTFLY3
                 
                        elif animToggle == 3:
                                djb.display.sprite(9, int(jetManX), int(jetManY)+8,djb.display.BLACK,WHITE_H_PAL)
               
                else:
                        djb.display.sprite(1, int(jetManX), int(jetManY),djb.display.BLACK,WHITE_H_PAL)
                        if animToggle == 0:
                                djb.display.sprite(11, int(jetManX), int(jetManY)+8,djb.display.BLACK,WHITE_H_PAL) # 11 JETMANLEFTFLY1
          
                        elif animToggle == 1:
                                djb.display.sprite(12, int(jetManX), int(jetManY)+8,djb.display.BLACK,WHITE_H_PAL) # 12 JETMANLEFTFLY2
                  
                        elif animToggle == 2:
                                djb.display.sprite(13, int(jetManX), int(jetManY)+8,djb.display.BLACK,WHITE_H_PAL) # 13 JETMANLEFTFLY3
          
                        elif animToggle == 3:
                                djb.display.sprite(12, int(jetManX), int(jetManY)+8,djb.display.BLACK,WHITE_H_PAL)


#=#=#=#=#=#=#=#=#=#=#=#=#=#=#=#=#=#=#=#=#=#=#=#=#=#=#=#=#=#=#=#=#=#=#=#=#=#=#=#=#=#=#=#=#=#=#=#=#=#=#=#=#=#=#=#=#=#=#=#=
def drawThings():
        global animToggle, gameDifficulty, bonusState, monsterType, fuelX, fuelY, bonusX, bonusY
        for index in range (0,gameDifficulty):
                x = monsters[index].x
                y = monsters[index].y
                direction = monsters[index].direction

                if monsterType == 0:
                        if direction == 1:
                            djb.display.sprite(39 if (animToggle%2) == 0 else 40, int(x), int(y),djb.display.BLACK,RED_H_PAL) # 39:ASTEROIDRIGHT1 40:ASTEROIDRIGHT2
                        else:
                            djb.display.sprite(41 if (animToggle%2) == 0 else 42, int(x), int(y),djb.display.BLACK,YELLOW_H_PAL) # 41:ASTEROIDRIGHT1 42:ASTEROIDRIGHT2
                if monsterType == 1:
                        djb.display.sprite(43 if (animToggle%2) == 0 else 44, int(x), int(y),djb.display.BLACK,GREEN_H_PAL)
                if monsterType == 2:
                        djb.display.sprite(45 if (animToggle%2) == 0 else 46, int(x), int(y),djb.display.BLACK,GREEN_H_PAL)
                if monsterType == 3:
                        if direction == 1:
                            djb.display.sprite(47 if (animToggle%2) == 0 else 47, int(x), int(y),djb.display.BLACK,YELLOW_H_PAL) # PLANE1
                        else:
                            djb.display.sprite(48 if (animToggle%2) == 0 else 48, int(x), int(y),djb.display.BLACK,YELLOW_H_PAL) #PLANE2
                if monsterType == 4:
                        djb.display.sprite(49 if (animToggle%2) == 0 else 49, int(x), int(y),djb.display.BLACK,WHITE_H_PAL) # CROSS

                if monsterType == 5:
                        if direction == 1:
                            djb.display.sprite(50 if (animToggle%2) == 0 else 50, int(x), int(y),djb.display.BLACK,WHITE_H_PAL) # FALCON1
                        else:
                            djb.display.sprite(51 if (animToggle%2) == 0 else 51, int(x), int(y),djb.display.BLACK,WHITE_H_PAL) # FALCON2
                if monsterType == 6:
                        djb.display.sprite(52 if (animToggle%2) == 0 else 53, int(x), int(y),djb.display.BLACK,WHITE_H_PAL) # UFO1 UFO2
                if monsterType == 7:
                        djb.display.sprite(54 if (animToggle%2) == 0 else 54, int(x), int(y),djb.display.BLACK,WHITE_H_PAL) # JELLY

                djb.display.sprite(27, int(fuelX), int(fuelY),djb.display.BLACK,MAGENTA_H_PAL) # 27 FUEL
                drawRocket()

                if bonusState != 0:
                        if bonusType == 0:
                                djb.display.sprite(28 if (animToggle%2) == 0 else 55, int(bonusX), int(bonusY),djb.display.BLACK,YELLOW_H_PAL) # 55 BLANK 28 DIAMOND
                        elif bonusType == 1:
                                djb.display.sprite(29 if (animToggle%2) == 0 else 55, int(bonusX), int(bonusY),djb.display.BLACK,MAGENTA_H_PAL)
                        elif bonusType == 2:
                                djb.display.sprite(30 if (animToggle%2) == 0 else 55, int(bonusX), int(bonusY),djb.display.BLACK,YELLOW_H_PAL)
                        elif bonusType == 3:
                                djb.display.sprite(31 if (animToggle%2) == 0 else 55, int(bonusX), int(bonusY),djb.display.BLACK,CYAN_H_PAL)
                        elif bonusType == 4:
                                djb.display.sprite(32 if (animToggle%2) == 0 else 55, int(bonusX), int(bonusY),djb.display.BLACK,BLUE_H_PAL)
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

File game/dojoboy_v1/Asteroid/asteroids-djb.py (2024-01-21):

#
# from https://gist.github.com/samneggs
#
# Modified By Yoyo Zorglup for the DojoBoy 2023 12 25
#

from dojoboy_v1 import DojoBoy

from machine import Timer
import math
from time import ticks_diff,ticks_us
from random import randint
from sys import exit
import _thread, array

# Initializing djb object
djb = DojoBoy(show_intro=True,width=160,height=128,framerate=30)

class Point():
    def __init__(self):
        self.x = 0
        self.y = 0
        self.ax = 0
        self.ay = 0
        self.c = 0
        self.exp = 0

class Ship():
    def __init__(self,ptdeg,ptrad,pts,tumble,x,y,size):
        self.x = x #randint(10,230)
        self.y = y #randint(10,125) 
        self.ax = randint(-2,2)/5
        self.ay = randint(-2,2)/5
        self.deg = 0
        self.size = size
        self.coll = self.size*5
        self.exp = 0
        self.damage = True
        self.pt = []
        self.ptrad = ptrad   # radius - points
        self.ptdeg = ptdeg   # degrees - points
        self.pts = pts       # number of points
        self.tumble = tumble # degress added for tumbling
        
#BL = 13
#DC = 8
#RST = 12
#MOSI = 11
#SCK = 10
#CS = 9
#LCD = LCD_1inch14()

m = []         # missile point list
p = []         # point list
a = []         # asteroid point list
e = []         # explode point list
asteroid = []  # big asteroids
t=[]           # title letters
let_rad= []
let_deg= []

let_deg.append([54,270,126,90,54])                      # A
let_rad.append([17,18,17,4,17])
#let_rad.append([9,10,9,2,9])

let_deg.append([306,270,234,54,90,126])                 # S
let_rad.append([17,18,17,17,18,17])

let_deg.append( [234, 306, 270, 90] )                   # T   
let_rad.append( [17, 17, 12, 14] )

let_deg.append( [306, 234, 0, 126, 54] )                # E
let_rad.append( [17, 17, 0, 17, 17] )

let_deg.append( [0, 306, 270, 234, 126, 191, 0, 60] )   # R
let_rad.append( [0, 17, 16, 17, 17, 10, 0, 16] )       

let_deg.append( [306, 270, 234, 126, 90, 54, 306] )     # O
let_rad.append( [17, 16, 17, 17, 16, 17, 17] )         

let_deg.append( [306, 270, 234, 270, 90, 54, 90, 126] ) # I
let_rad.append( [17, 16, 17, 14, 14, 17, 16, 17] )

let_deg.append( [234, 270, 0, 90, 126, 234] )           # D
let_rad.append( [17, 14, 10, 14, 17, 17] )

let_deg.append([306,270,234,54,90,126])                 # S
let_rad.append([17,18,17,17,18,17])



token = 0      # muli-thread nonesense
gticks = 0
rfire = 0
threaded = False
num_asteroids = 3 # number of asteroids to start

isin=array.array('i',range(0,361))
icos=array.array('i',range(0,361))

def timed_function(f, *args, **kwargs):  # for timing defs
    myname = str(f).split(' ')[1]
    def new_func(*args, **kwargs):
        t = ticks_us()
        result = f(*args, **kwargs)
        delta = ticks_diff(ticks_us(), t)
        print('Function {} Time = {:6.3f}ms'.format(myname, delta/1000))
        return result
    return new_func


def init_isin():            # integer sin lookup table    
    for i in range(0,361):
        isin[i]=int(math.sin(math.radians(i))*100000)

def init_icos():            # integer cos lookup table 
    for i in range(0,361):
        icos[i]=int(math.cos(math.radians(i))*100000)


def init_title():
    for i in range(0,9):
        #t.append(init_obj(let_deg[i],let_rad[i],len(let_deg[i]),1,10+i*26,50,1))
        t.append(init_obj(let_deg[i],let_rad[i],len(let_deg[i]),1,1+i*20,50,1))
        t[i].ax=0
        t[i].ay=0
        draw_object(t[i])
    
    djb.scan_jst_btn() #scan buttons
    
    while djb.pressed(djb.btn_Start)==0:
        djb.scan_jst_btn() #scan buttons
        for i in t:
            draw_object(i)
        djb.display.show()
        
    for i in t:
        init_explode(i,50,.5)
        while len(e)>5:
            explode()           
            djb.display.show()
        explode_cleanup()
        i.size=0
        draw_object(i)
        #djb.display.show()
    djb.display.fill(djb.display.BLACK)
    

def init_obj(ptdeg,ptrad,pts,tumble,x,y,size):
    obj = Ship(ptdeg,ptrad,pts,tumble,x,y,size)                    #reset obj
    for i in range(0,obj.pts*3):
        obj.pt.append(Point())
    return obj

def init_ast():                      # old dot asteroids
    for i in range(0,6):             # 6 number of asteriod dots
        a.append(Point())
        a[i].x=randint(0,160)        # random location
        a[i].y=randint(0,128)
        a[i].ax=randint(-10,10)/30   # set speed
        a[i].ay=randint(-10,10)/30 

def init_asteroids():
    global num_asteroids
    for i in range(0,num_asteroids):   
        asteroid.append(init_obj([0,60,120,180,240,300,0],[7]+[randint(6,9) for _ in range(5)]+[7],7,randint(-3,3),randint(10,230),randint(10,125),3))

def draw_object(obj):
    global token
    token = 0
    for i in range(0,obj.pts-1):
        djb.display.line(obj.pt[i].x,obj.pt[i].y,obj.pt[i+1].x,obj.pt[i+1].y,djb.display.BLACK) # erase old obj
        
    if (obj.exp == 0 and obj.tumble==0) or (obj.size>0 and obj.tumble!=0):
        move_object(obj)
        if ship.damage==False:
            c=djb.display.RED_H
        else:
            c=djb.display.GREEN_H
        for i in range(0,obj.pts-1):
            djb.display.line(obj.pt[i].x,obj.pt[i].y,obj.pt[i+1].x,obj.pt[i+1].y,c) # draw new obj
    token = 1

def slow_ship():
    if ship.ax > 0:                         # slow ship down automatically 
        ship.ax=ship.ax - 0.01
    if ship.ay > 0:
        ship.ay=ship.ay - 0.01
    if ship.ax < 0:
        ship.ax=ship.ax + 0.01
    if ship.ay < 0:
        ship.ay=ship.ay + 0.01
    if ship.ax < 0.01 and ship.ax > -0.01:  # if very slow then stop
        ship.ax = 0
    if ship.ay < 0.01 and ship.ay > -0.01:
        ship.ay = 0


def move_object(obj):
    obj.x+=obj.ax                   # add accel to x,y
    obj.y=obj.y+obj.ay
    if obj.x > 160:                 # wrap around if out of bounds
        obj.x = 0
    if obj.x < 0:
        obj.x = 160
    if obj.y > 128:
        obj.y = 0
    if obj.y < 0:
        obj.y = 128
    obj.deg+=obj.tumble             # add tumble to deg
    if obj.deg>359:
        obj.deg-=360
    if obj.deg<0:
        obj.deg+=360

    for i in range(0,obj.pts):
#         rad=math.radians(obj.deg+obj.ptdeg[i])
#         obj.pt[i].x=int(obj.ptrad[i]*math.cos(rad)+obj.x)  # point i of obj
#         obj.pt[i].y=int(obj.ptrad[i]*math.sin(rad)+obj.y)
        
        deg=int(obj.deg+obj.ptdeg[i])
        if deg>359:
            deg-=360
        obj.pt[i].x=int(obj.ptrad[i]*obj.size*icos[deg]/100000+obj.x)   
        obj.pt[i].y=int(obj.ptrad[i]*obj.size*isin[deg]/100000+obj.y)



def thrust():
#     rad=math.radians(ship.deg)
#     ship.ax=ship.ax+math.cos(rad)/15   # add accel in direction ship is pointed
#     ship.ay=ship.ay+math.sin(rad)/15

    ship.ax=ship.ax+icos[ship.deg]/100000/15   # add accel in direction ship is pointed
    ship.ay=ship.ay+isin[ship.deg]/100000/15
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

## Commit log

2024-01-21 Fix import lib in games and add workshops
    [asteroids-djb.py, defender-djb.py]
2024-01-28 Update Schematic
2024-02-11 Add Schematic Board Wiring
2024-02-17 Add STL Files
    [DojoBoy-Model A-Bottom.stl, DojoBoy-Model A-JoyFix.stl, DojoBoy-Model A-Top.stl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]
2024-03-18 Update STL,PCB,Doc,Lib
    [DojoBoy-Model A-Bottom.stl, DojoBoy-Model A-JoyFix.stl, DojoBoy-Model A-Top.stl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]
2024-03-18 Update PCB images
